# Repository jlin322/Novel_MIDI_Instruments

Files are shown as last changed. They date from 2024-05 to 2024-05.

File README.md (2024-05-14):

# Novel_MIDI_Instruments

## Overview
ECD 423 Novel MIDI Instruments is a Senior Capstone Project from 2023-2024. The purpose of this project was to design a creative Novel MIDI Instrument capable of polyphony, pitch bend and variable volume control. The product would utilize the functions of a synthesizer. This project is using the open-source synthesizer, Element. The general design consists of a detachable L-shaped rail which can fit on any ordinary tripod boom mic stand. The product consists of 2 keypads and a base station. The base station contains a tilt detection system and is fixed to the center of the rod. Depending on the location of the keypad on the rail, both keypads’ orientation as well as angle of rod tilt, the MIDI device is able to switch between different instruments. The 2 keypads are able to freely slide up and down the rod and act as the inputs for the user to control the available instruments on the mic stand. The entire system consists of 3 microcontrollers and 3 nRF24L01 transceiver modules. The transceiver modules create a long signal transmission line which works to send MIDI signals from the moment the user presses on a key or input device to the moment a note is emitted from the synthesizer.

## Final Design Product

<p float="left">
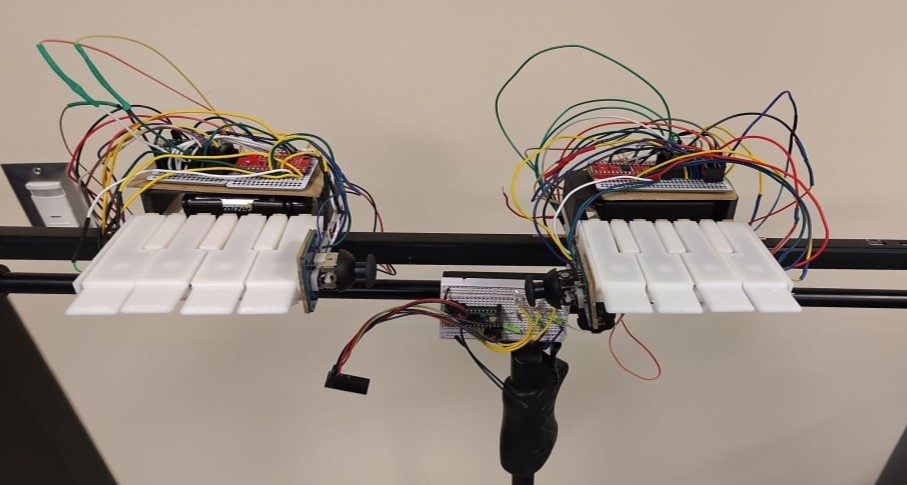
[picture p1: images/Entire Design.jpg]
 
</p>
An image of the Novel MIDI Instrument with both keypads and base station assembled on the tripod boom mic stand.

## Arduino IDE Setup

### Libraries Installation
1. **Control Surface Library by tttapa**
2. **Joystick by Giuseppe Martini**
3. **RF24 by TMRh20**
4. **light_CD74HC4067 by SunitRaut**
5. **Encoder by Paul Stoffregen**
6. **SPI**

### Code Upload

1. Upload the code from `FinalTest_TxL` to the left keypad.
2. Upload the code from `FinalTest_TxR` to the right keypad.
3. Upload the code from `FinalTest_Rx` to the base station.

### Plugin and Synthesizer Setup

1. Download all plugins from the provided plugin folder.
2. Download the synthesizer program "Kushview Element."
3. Open `NovelMIDISynth.els` from the Synthesizer Plugins & Session Folder in Element.

### Synthesizer Configuration

1. In Element, navigate to `File` > `Preferences` > `MIDI` and select "Control Surface Library" if not already chosen.
2. Exit the preferences screen and double-click on the MIDI Monitor as shown in Figure i below.

<p float="left">
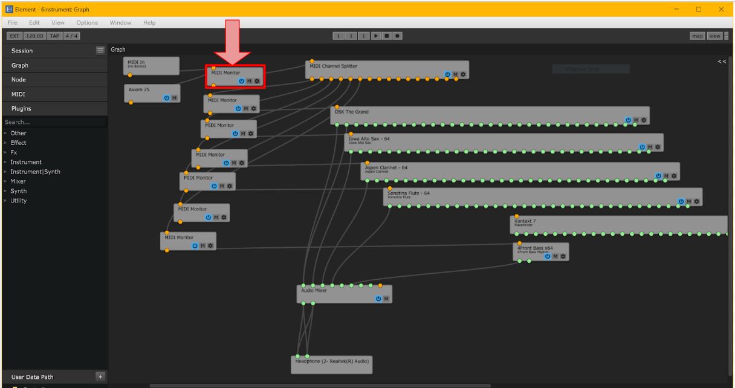
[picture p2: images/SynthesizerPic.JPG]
 
</p>
The image above shows the connections for all plugins within the synthesizer program.
By following these steps, you'll have the necessary components installed, codes uploaded, and synthesizer configured for your project.

## Credits
- Team Members: Sean MacHaffie, Rohan Giridharan, Baron Li

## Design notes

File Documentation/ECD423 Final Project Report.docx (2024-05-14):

# ECD423 Novel MIDI Instrument

# Project Report

2024-05-03

Submitted by:

Sean MacHaffie, Project Lead, Computer Engineering

Baron Li, Finance Manager & Testing Lead, Computer Engineering

Jolin Lin, Software Lead, Computer Engineering

Rohan Giridharan, Electrical & Communication Lead, Electrical Engineering

Project Advisor: Prof. Scott Craver

Approved for public release; distribution is unlimited.

Submitted in partial fulfillment of ECD academic requirements.

Thomas J. Watson College of Engineering and Applied Science

Binghamton University

Binghamton, NY

Abstract

ECD 423 Novel MIDI Instruments is a Senior Capstone Project from 2023-2024. The purpose of this project was to design a creative Novel MIDI Instrument capable of polyphony, pitch bend and variable volume control. The product would utilize the functions of a synthesizer. This project is using the open-source synthesizer, Element. The general design consists of a detachable L-shaped rail which can fit on any ordinary tripod boom mic stand. The product consists of 2 keypads and a base station. The base station contains a tilt detection system and is fixed to the center of the rod. Depending on the location of the keypad on the rail, both keypads’ orientation as well as angle of rod tilt, the MIDI device is able to switch between different instruments. The 2 keypads are able to freely slide up and down the rod and act as the inputs for the user to control the available instruments on the mic stand. The entire system consists of 3 microcontrollers and 3 nRF24L01 transceiver modules. The transceiver modules create a long signal transmission line which works to send MIDI signals from the moment the user presses on a key or input device to the moment a note is emitted from the synthesizer.

Table of Contents

1 Introduction 1

1.1 System Overview 1

1.2 Document Overview 1

2 Referenced Documents 1

3 Problem Definition 1

3.1 Problem Scope 1

3.2 Technical Review 2

3.3 Design Requirements 2

3.3.1 Original Proposed Requirements 2

3.3.2 Derived Requirements 2

3.3.3 Stretch Goals 2

4 System Design 3

4.1 System-Wide Design Decisions 3

4.2 System Components and Interfaces 5

4.3 Concept of Execution 6

4.4 Hardware Design 7

4.5 Software Design 9

4.6 Safety Considerations 11

4.7 Environmental Impact 11

5 Project Development 11

5.1 Risk Abatement 11

5.2 Project Schedule 12

5.3 Project Finances 12

6 System Implementation 13

7 Project Evaluation 13

7.1 Overview 13

7.2 Testing and Results 13

7.3 Assessment 13

7.4 Future Potential 13

8 Notes 14

8.1 Acronyms and Abbreviations 14

8.2 Bibliography 14

8.3 References 14

9 Appendices 15

9.1 Appendix A - Project Specifications Document 15

9.2 Appendix B - Financial Status Table 17

9.3 Appendix C - Code for Base Station(Receiver) 19

9.4 Appendix D - Code for Left Keypad(Transmitter) 59

9.5 Appendix E - Code for Right Keypad(Transmitter) 63

9.6 Appendix F - INT Plan 67

9.7 Appendix G - Demonstration Saxophone Fingering Chart 77

9.8 Appendix H - Parts List 86

9.9 Appendix I - Project Standards 86

9.10 Appendix I - Requirements Impact Assessment 87

List of Figures

Figure 1: Top Plate

Figure 2: Base Plate

Figure 3: High Level Keypad Design

Figure 4: High Level Base Station Keypad Design

Figure 5: Final Keypad Design, showing the 4 lamellophone keys at the bottom and the location of the pitch bend joystick

Figure 6: Preliminary Keypad Design, modeled off a traditional keyboard

Figure 7: Second Keypad Design

Figure 8: Outermost white keys, including lamellophone key attachments. At the back is a hook to attach a rubber band. There is a corresponding hook on the base plate.

Figure 9: Center white keys. These two keys are a slightly different shape than the outermost keys, allowing them to fit better in the base plate

Figure 10. Black key. All keys have a post at the front, which allows them to make proper contact with the force sensitive resistors below

Figure 11. Data Structure that is received by the base station.

Figure 12. Data Structure that holds variables for each key and determines which notes are going to be sent to the synthesizer.

Figure 13. Gantt Chart for the Fall Semester

List of Tables

Table 1. Order Breakdown

# 1 Introduction

## 1.1 System Overview

This report is for the ECD423 Novel MIDI Instrument project of 2023-2024.

The purpose of this project is to create a Novel MIDI Instrument that is capable of polyphony, variable volume control and pitch bend. The design can be described as a detachable metal rail with 2 sliding keypads, a tilt detection system and a base station which is attachable to the lifting tube of the microphone stand. The base station sends signals to the synthesizer via USB connection. The device is capable of being attached to a tripod boom microphone stand without inhibiting the microphone stand's original functionality. The user is able to play a variety of instruments on the microphone stand. Keypad rotation, keypad location on the rail and rod tilt are taken into account in order to switch between different instruments. The user is able to control the type of notes being produced by the synthesizer using keys on the keypad as well as location of the keypad on the rail. Sliding the keypads up and down the rod can produce note changes depending on what instrument is being played.

## 1.2 Document Overview

This report provides the essential project requirements in Section 3, Requirements, along with some non-essential stretch goals.

In this specification, a requirement is identified by “shall”, a good practice by “should”, permission by “may” or “can”, expected outcome or action by “will”, and descriptive material by “is” or “are” (or another verb form of “to be”).

# 2 Referenced Documents

The following documents of the exact issue shown form a part of this report as specified herein.

A. ECD423: Novel MIDI Instrument Project Specifications Document

# 3 Problem Definition

## 3.1 Problem Scope

For musicians, there exists the problem of practicality when playing multiple instruments at the same time. This problem becomes more prevalent for people who enjoy playing as one man bands. Time wasted having to set up each individual instrument on stage, along with having to switch from one musical device to another as well as the difficulty of having to carry these instruments from place to place proves challenging and impractical. The goal of this project is to design and create a Novel MIDI Instrument capable of polyphony, pitch bend and variable volume control. The final product is able to imitate the abilities of a typical instrument as well as switch between multiple different instruments as well.

## 3.2 Technical Review

The device was created with the intent of being an attachable object onto a typical microphone stand. The product should not inhibit the functions of a regular microphone stand whilst imitating instruments. One advantage that the consumer should notice includes time efficiency when switching from 1 instrument to another. For example, the user would simply need to tilt the metal rod 90 degrees, allowing it to point upwards towards the ceiling, and rotate the left keypad 180 degrees to transition from piano mode to bass guitar mode. This is assuming that the position the user was in prior to the transition allowed the device to be in piano mode. Another advantage includes the ease of learning how to use this product. Since the design is a collection of ordinary musical instruments, users will rarely feel like they need to learn an entirely different skill set to play this device. The instrument modes available on the device were designed to take after the orientation of the instruments and the positioning of the hands for a typical person playing that specific instrument. In this way, users need only remember how they would typically play an instrument and imitate that on the Mic Stand.

## 3.3 Design Requirements

The contents below contain the original/derived requirements and stretch goals. A tabled version of this is included in the Appendix section of this document.

### 3.3.1 Original Proposed Requirements

1. The MIDI instrument shall be able to produce polyphony, pitch bend and variable volume control. {ECD423-R-001}
2. The MIDI instrument shall be able to produce pitch bend. {ECD423-R-002}
3. The MIDI instrument shall be able to produce variable volume control. {ECD423-R-003}
4. It shall output accurate MIDI signals to the synthesizer. {ECD423-R-004}

### 3.3.2 Derived Requirements

1. The device shall not inhibit the functions of an ordinary microphone stand. {ECD423-R-005}
2. Both keypads will be capable of rotation and sliding movement on the rod. {ECD423-R-006}
3. The device shall be able to switch between at least 6 different instruments based on keypad rotation, keypad location on the rod, and rod tilting motion. {ECD423-R-007}
4. There shall be wireless communication between the keypads and base station. {ECD423-R-008}
5. The device shall be able to detect the position of both keypads on the rod at any given time. {ECD423-R-009}
6. The base station shall have the capability to differentiate between 3 positions on the rod: horizontal, vertical and angled. {ECD423-R-010}
7. MIDI signals shall travel from the base station to a synthesizer via USB connection. {ECD423-R-011}

### 3.3.3 Stretch Goals

1. The response time between note pressing and note emission from the synthesizer should be less than 10ms. {ECD423-G-001}
2. The instrument should be able to synthesize sound directly from the product. {ECD423-G-002}
3. Both keypads should have an electronic locking/unlocking mechanism to secure its position on the rod when locked and allow for movement when unlocked. {ECD423-G-003}
4. The device should be able to switch between at least 10 different instruments based on keypad rotation, keypad location on the rod, and rod tilting motion. {ECD423-G-004}
5. The device should have 4 lamellophone style keys which are attached to force sensors and produce sound reminiscent of strumming string instruments. {ECD423-G-005}

# 4 System Design

## 4.1 System-Wide Design Decisions

    4.1.1 Keypad Position: For deciding how to measure the keypads position along the rod there were three options: digital caliper, rotary encoder, and optical mouse sensors. The rotary encoder was chosen for ease of use. Using a readily available Encoder library, the rotary encoder was easily interfaced with the Teensy microcontroller. As the technology of an PS2 optical mouse is more outdated, it was difficult to find a suitable mouse and library. The final option was to imitate a digital caliper. There are no readily available components to make this option possible. This option was dismissed due to time constraints.
    4.1.2 Tilt Detection: To measure rod tilt, there were 3 different options. The first option was a mercury tilt sensor, a time-of-flight sensor, and a metal ball tilt sensor. The option that was chosen was the metal ball tilt sensor. This option was chosen due to the simplicity of its implementation. The mercury tilt sensor was dismissed due to environmental concerns, in case the sensor were to break.. The time-of-flight sensor was difficult to connect with the base station in an accurate way. The constantly changing environment of the tilting microphone stand caused inaccurate measurements.
    4.1.3 Key Measurement: To measure variable volume, the project utilizes force sensitive resistors. These were chosen due to the ease of implementation. Pushing on these force sensitive resistors with the piano keys gives a variable analog value based on the force of the key press. This analog value was easily tied to the variable volume in the synthesizer software.

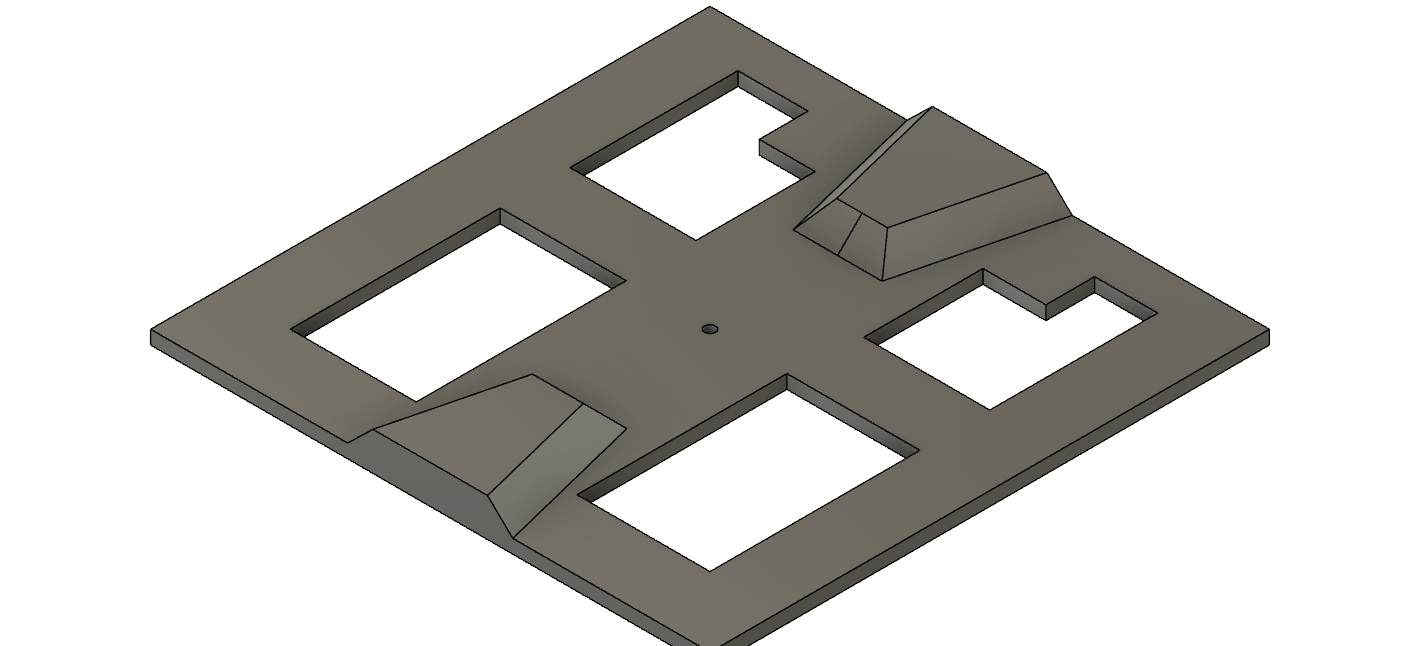
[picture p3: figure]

Figure 1: Top Plate

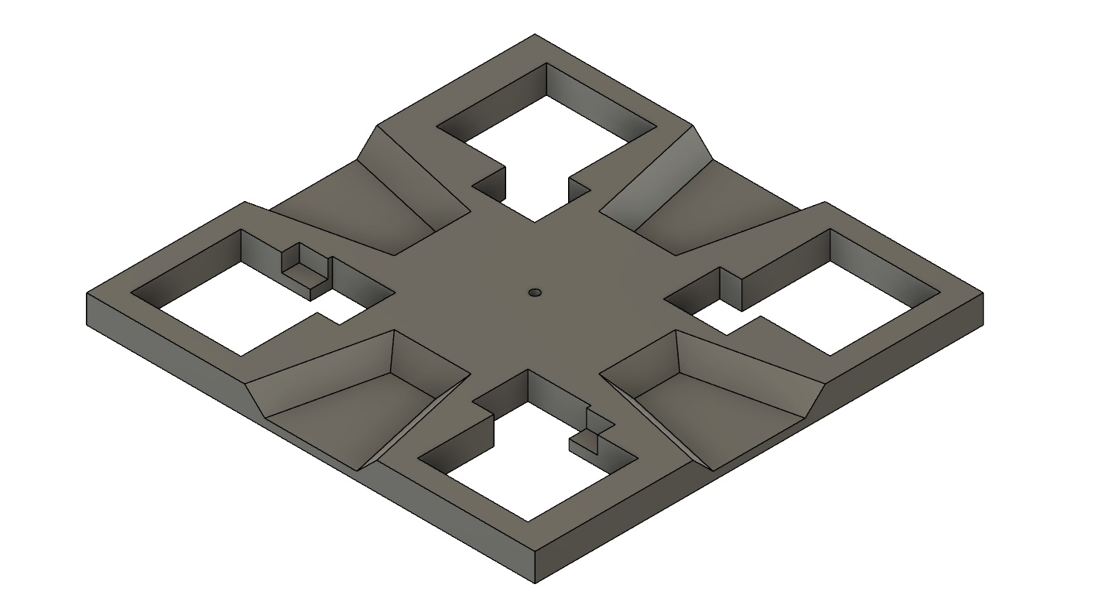
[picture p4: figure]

Figure 2: Base Plate

    4.1.4 Rotation: The device has rotating keypads. To accomplish this the keypad has a rotation base plate and top plate shown in figure 1 and 2 respectively. The top plate has contacts that are connected to pull-up resistors which will identify four different rotation positions (up, down, left, right).

## 4.2 System Components and Interfaces

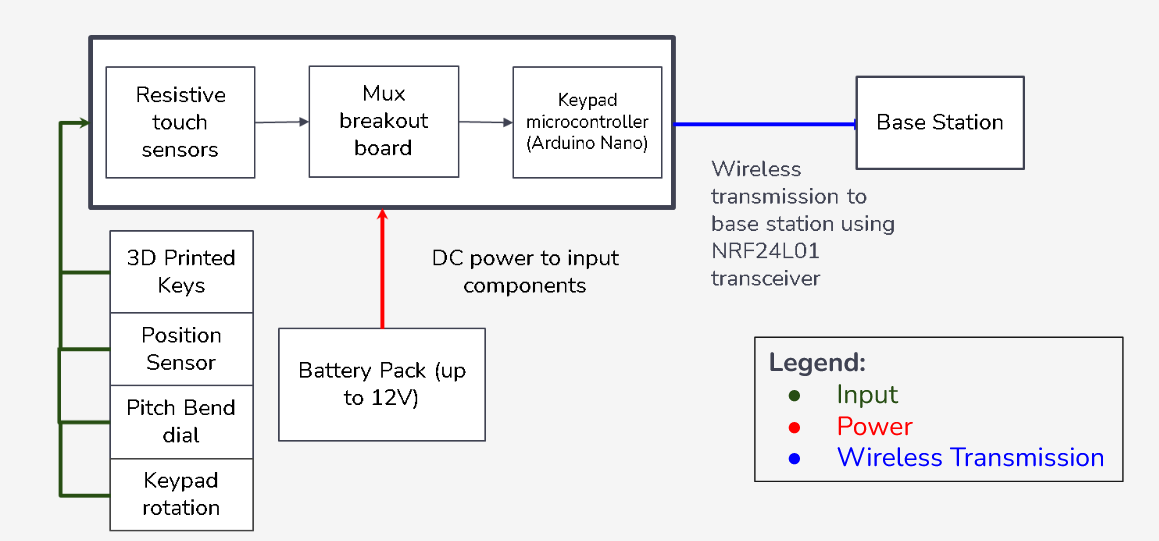
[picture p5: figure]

Figure 3: High Level Keypad Diagram

    4.2.1 Keypad: The instrument has two sliding keypads. Each keypad will contain seven force sensitive resistors, one rotary encoder, one NRF2401 wireless transceiver, one analog multiplexer breakout board, one two-axis joystick, and one microcontroller. The microcontroller takes all the inputs and sends them to the base station in a struct. The microcontroller was chosen for its small form factor. The multiplexer breakout board is implemented to allow enough input ports for the keypad components. The seven force sensitive resistors (FSR) are implemented under the seven 3D printed keys. Each FSR provides an analog signal to the microcontroller board, and just as in a traditional keyboard, the harder the key is pressed, the louder the note that is played. The left keypad’s two-axis joystick is used for pitch bend, while the joystick on the right keypad is used to mimic a breath in the woodwind modes. The joysticks are located on the side of the keypad, intended to be positioned under a users’ thumb on each keypad. The NRF24L01 transceiver module is used to wirelessly transmit data. A rotary encoder outputs a value that will increase or decrease to indicate which direction it is turning. The software constantly updates this value starting from a known zero position to accurately track the position of the keypad with this method.

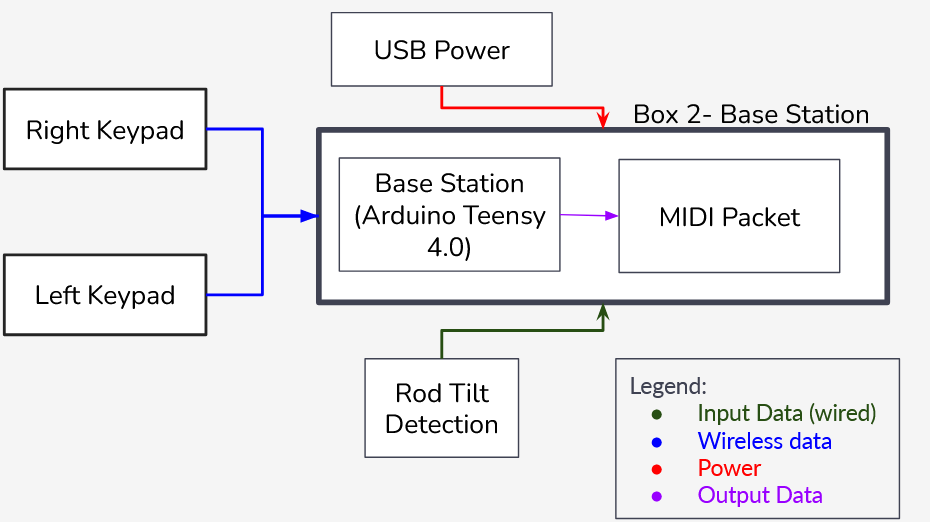
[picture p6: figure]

Figure 4: High Level Base Station Keypad Diagram

    4.2.2 Base Station: The instrument has one base station. The base station will use an Arduino Teensy 4.0 microcontroller. The Teensy was chosen for its USB communication capability and its size. The purpose of the base station is to receive wireless data from the keypads. Additionally, the base station has three metal ball tilt sensors that are used to determine the tilting mode of the instrument, whether it be horizontal, vertical or tilted. By combining the tilt motion with the position and rotation of the keypad, this allows the user to change to a number of instruments. Using the MIDIUSB Arduino library, the base station creates a MIDI message which will be sent over USB to the external synthesizer software Element and outputted over the computer speakers.

## 4.3 Concept of Execution

The target audience uses the MIDI device via interactions with the 2 keypads which rests on the detachable rail. The keypads are ergonomically designed for the left and right hands. The user can determine the orientation of each keypad based on the location of the joystick which is attached to the inside of the keypads. Ideally, the correct orientation of the left keypad for the consumer is one where the joystick is located on the right side of the keypad and the keys are faced in a similar way like a piano. In the instance where the device is in piano mode, this means that the user has allowed the rail to run parallel to the ground with both keypads facing towards him. The device recognizes the switching to this particular instrument mode in part due to the tilt detection system which is made up of tilt switches that turn on and off when the rod is at different angles. The location of the keypad on the rail serves as a crucial aspect in this design. The user can play a variety of notes similar to that of a piano when in piano mode. The inner workings to make this possible involve the transmission of signals produced when the user hits a key. A signal gets generated and travels through an Arduino Nano to a wireless transceiver which then is accepted by a receiver on the base station to a Teensy where the MIDI signal is finally sent to the synthesizer for the correct note to be emitted. This isn’t the only thing that is sent through the transmission line because underneath each key lies a force resistive sensor which collects the pressure exerted by the user on the keys. The range of pressure applied to these keys controls the volume at which the user wants to emit the notes at. The consumer would only need to exert more pressure when wanting to evoke a louder note and exert less pressure for the opposite effect. Moving the joystick in different directions allows the audience to control pitch bend to produce a musical effect of notes sliding into other notes. This information is also sent along the transmission line to be unpackaged and in the Teensy. Since the keypads communicate wirelessly, each keypad will have a rechargeable battery while the base station is powered by the laptop via USB connection. To break this connection and shut off the system, the user only needs to disconnect the laptop from the base station.

## 4.4 Hardware Design

All 3D models for hardware components were made in Autodesk Fusion 360. This includes the following: white and black keys, a keypad base, rotation mechanism (shown in section 4.1.3) and a slider attachment. While brainstorming, there were multiple keypad designs before the final design shown in Figure XI. The first design was modeled off what would be found on a traditional keyboard, which is shown in figure XII. The lamellophone design was chosen as it would allow the user to be able to play instruments like a bass or a guitar, which require a plucking or strumming motion. This design is not conducive to strumming, and would therefore be extremely impractical and difficult to implement. Implementing this design would also result in a lot of additional hand movement to change the set of notes that were being played. The second design (Figure XIII) consisted of 5 white keys and 4 black keys, where the black keys would be positioned in such a way that they could be used as an analog for the strumming instruments. The black keys would be sufficiently high above the white keys and would require a spring mechanism that could provide a somewhat stringlike motion. While far more practical than the first design, implementing this design would have required a lot of testing to find not only the right kind of spring, but also the necessary actuation force. This would have taken up a lot of valuable time during the spring semester. The current design is a refinement of design 2, adding the lamellophone keys at the bottom of the keypad to imitate a string instrument, as well as a joystick for pitch bend on the side, in reach of the user’s thumb. After coming up with the final keypad design, the models were created for the keypad base, and the black, white and lamellophone keys. There are three different versions of the white keys, one for the left side, one for the right side and one for the two center keys. At the end of the white and black keys, there is a hook, which will be used as an attachment point for the rubber bands to ensure the key returns to its original position after being pressed. Rather than use a spring, rubber bands were used as the actuation force could be easily tuned by simply changing the amount of rubber bands, rather than swapping out the entire spring. As was the case with keypad design 2, this will ultimately save a lot of time while testing. All keys have a post at the front, which allows them to make proper contact with the force sensitive resistors (FSRs) below. As with a traditional piano, the harder you press on the keys, the louder the sound of the note.

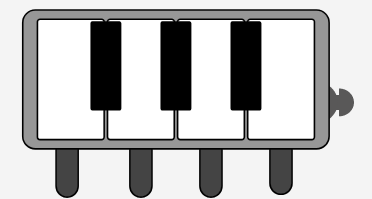
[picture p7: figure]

Figure 5: Final Keypad Design, showing the 4 lamellophone keys at the bottom and the location of the pitch bend joystick

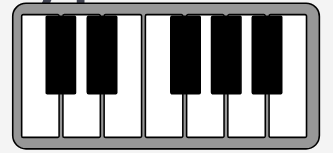
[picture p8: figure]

Figure 6: Preliminary Keypad Design, modeled off a traditional keyboard

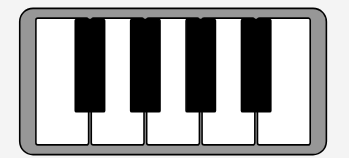
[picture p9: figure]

Figure 7: Second Keypad Design

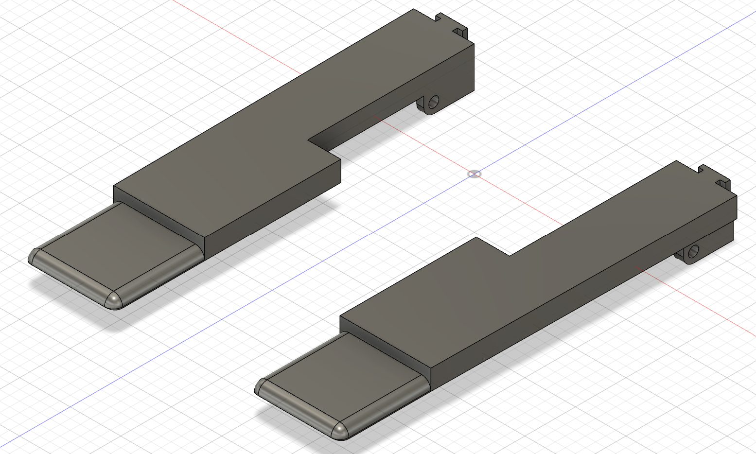
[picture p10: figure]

Figure 8: Outermost white keys, including lamellophone key attachments. At the back is a hook to attach a rubber band. There is a corresponding hook on the base plate.

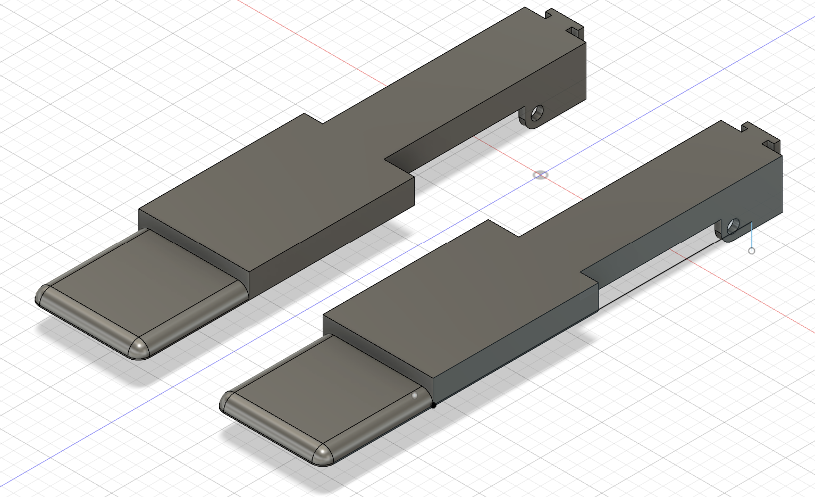
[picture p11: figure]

Figure 9: Center white keys. These two keys are a slightly different shape than the outermost keys, allowing them to fit better in the base plate

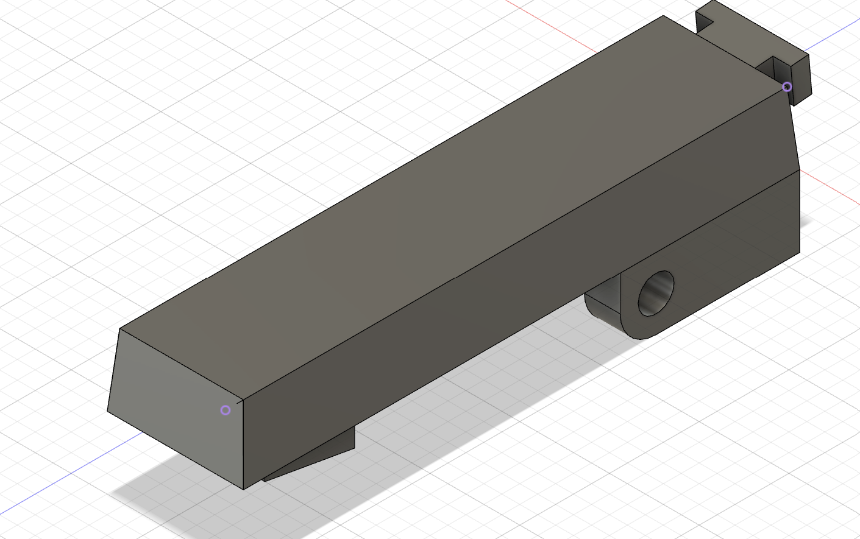
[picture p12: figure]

Figure 10: Black key. All keys have a post at the front, which allows them to make proper contact with the force sensitive resistors below

## 4.5 Software Design

All software that was constructed was created using Arduino IDE. The final programmed files were only created after running multiple demos which involved manipulating a set of test signals to send them to their ultimate destination, the Element synthesizer. Demo code for this project started off with MIDI signals traveling close to the synthesizer relative to the entire transmission line that the signal would eventually have to pass through from start to finish. The program experimented with using a backwards approach by first sending MIDI signals from the base station micro controller to the synthesizer directly through a USB connection. Wireless communication between the base station and keypads were established with two nRF24L01 set to transceiver mode in the keypads and the final nRF24L01 set to receiver mode in the base station. This allowed consistent one directional communication between the keypads and the base station when the system was on. Code was then generated once the Arduino Nano’s on each keypad were connected to the wireless transceivers to send test signals starting from the Nano and traveling through the transmission pipe to the synthesizer. The final step in this was performed through a combination of circuitry knowledge and programming skills, as the test signals no longer needed to be hard coded onto the board. Rather a test user would press on the keys themselves to generate signals. The same was done for the joysticks. During this entire process, all demo programs were consolidated into one location with proper formatting and comments for readability and correct interpretation of program intent.

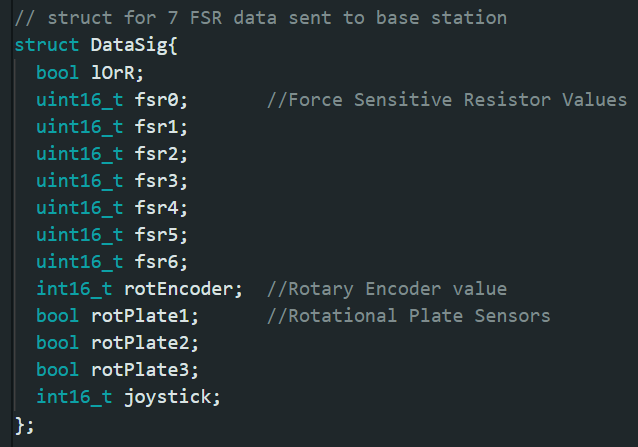
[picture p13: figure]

Figure 11: This is the data structure that is received by the base station.

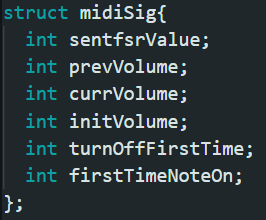
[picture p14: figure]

Figure 12: This structure holds variables for each key and determines which notes are going to be sent to the synthesizer.

The final code contains three general programs which had to be uploaded to both keypads and the base station. Please note that the file name demo13_finalTestTxL contains code for the left keypad while demo13_finalTestTxR is meant for the right. Since both keypads differ slightly by the soldering of different pins, both keypads must have independent files. Moving on, the file demo13_finalTestRx is code for the receiver or base station. In summary, the receiver code takes data signals from both transmitters and saves them in separate structures. Data within these structures use the switchInstruments() function to determine which instrument setting the device is on. Depending on the instrument mode, certain functions may be invoked which ultimately determine the instructions to send to the synthesizer. Instructions that may be used include sending notes on or off, which notes to play, what instrument channel to play them with, what volume to play it on and whether there is pitch bend or not.

## 4.6 Safety Considerations

In the brainstorming process of the novel instrument, ensuring safety was a key consideration in the design discussion. Instead of employing mercury tilt switches for the rod tilt detection, the design opts for metal ball tilt switches. Mercury is classified as a toxic heavy metal. In consideration of health and environmental concerns, the mercury tilt switches were excluded from consideration. All wiring will be discreetly embedded within the instrument housing, eliminating potential environmental hazards with exposed wires.

## 4.7 Environmental Impact

As mentioned in the safety considerations, the environmental impact was an important consideration when designing the instrument. The metal ball tilt switches do not have the same environmental risk of mercury contamination. The keypads will be powered with a rechargeable battery pack. This choice was made with sustainability in mind, and eliminates the need for battery replacements and minimizes the waste in comparison to single-use disposable batteries. The housings and keypads are created with CAD and printed with ABS plastic, a commonly used thermoplastic in 3D printing. ABS plastic is durable, safe for consumer use, and can be melted and recycled.

# 5 Project Development

## 5.1 Risk Abatement

Some risks that may affect this project are: integration of many different hardware components, too many inputs into the microcontroller, and total propagation time from note press to sound output. To mitigate these risks, all components are tested and verified separately before integration. All ordered components must also be well-documented. To resolve the potential error of not having enough inputs into the microcontroller, a multiplexer breakout board was procured. To mitigate the propagation time, a low latency wireless standard was selected. The design utilizes low latency components such as the NRF24L01 transceiver.

## 5.2 Project Schedule

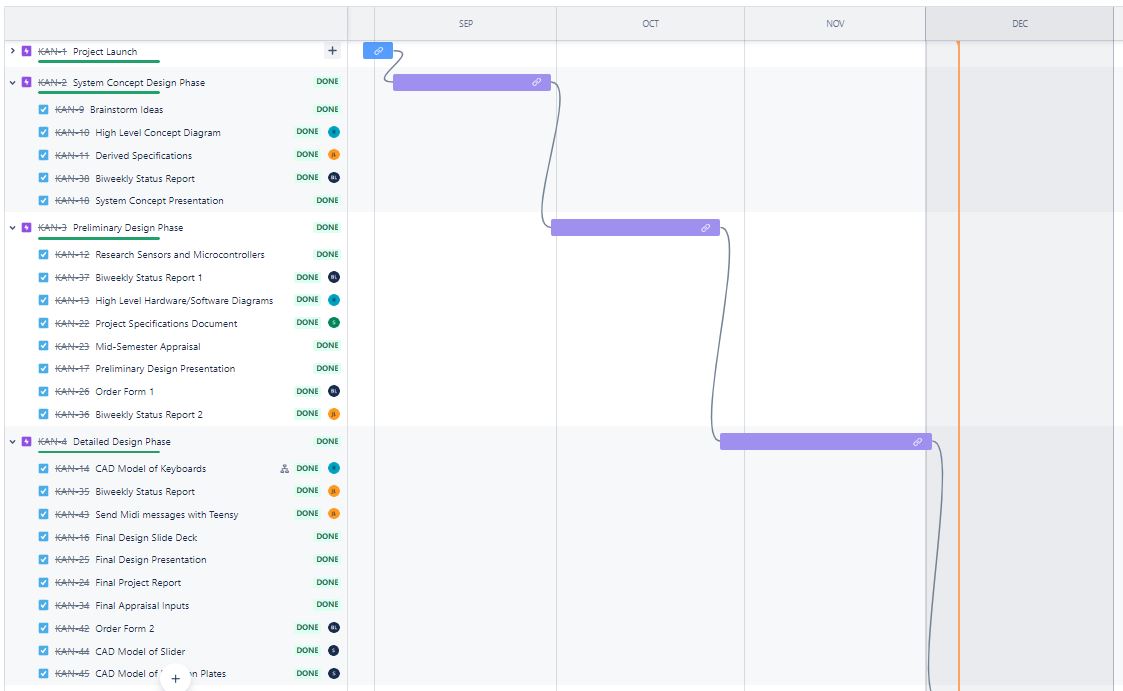
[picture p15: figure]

Figure 11: Gantt Chart for the Fall Semester

The project was formally launched on September 1st, 2023. After a brainstorming process, a list was compiled for September.. Research for sensors began in October and early CAD designs for housing components were proposed. The team created high level software and hardware diagrams. The design was finalized in early November, as testing began for some of the sensors and components. Test programs for the MIDI synthesizer and controller were made to successfully generate MIDI signals using the Arduino Teensy and the Element software. Final keys and keypad designs were made and ready to be printed. Throughout the Spring semester, the sensors were integrated into the base station and keypads. After integrating the components together on the microphone stand, thorough testing, calibrating and debugging was done to finalize the prototype.

## 5.3 Project Finances

A budget of $800 has been allocated to the project’s fulfillment. Electronic equipment and materials were provided by the Seymour Kunis Media Core. A breakdown of the order cost can be seen in Appendix B. As the Novel MIDI Instrument designed for this project was complex, it had surpassed the expected expenditure of $150 - $200 as seen in previous iterations of the project. Due to the high cost of the required sensors and the extensive testing for optimal and compatible components, a total of approximately $400 was spent. As not all of the ordered sensors were used in the final design, the cost of the prototype would be closer to $200.

# 6 System Implementation

The final design contains the 2 keypads with a base station. The electronics of the keypads were assembled with a soldered project board, with some pin extenders that were used to plug in some components so they could be removable. This was done to the Teensy that is on board along with the pins for the rotary encoder, the pins for the NRF24L01 transceiver and battery.

For better use of the rotary encoder, a gear was attached on the knob of the encoder and a track along the rail to ensure that no rotations were missed when the keypad moved along the rod. to attach the keypads top and bottom plate, a screw attached to an U shaped piece of 3d printed plastic which acted as a spring. This ensured that the top plate had enough pressure to attach to the base plate but could be lifted and rotated by the user.

To power the keypads, AA batteries were used. Due to the limited supplies of the Seymour Kunis Media Core, one keypad was powered by 4 AA batteries and the other keypad was powered by 3 AA batteries. The 4 AA batteries worked better due to a longer battery life and better counter weight for the keypad.

For the actual keyboard, a 10-gauge wire was inserted as an axle for all the individual keys to rest on. Orthodontic elastic bands functioned well with the axle to keep the keys in a default position. The bands were also readily available in the Media Core. A spacer was added below the keypad so the bands can be changed after assembly.

The base station and the tilt sensor were combined into one unit for simplicity. The tilt sensor was left on a solderless breadboard due to the position of the metal ball tilt switches being very important. This station was attached to the rod with some trouble sided tape.

# 7 Project Evaluation

## 7.1 Overview

To evaluate this project, it was demonstrated that each test could be independently performed. After proving successful, the goal was to integrate the systems to test again.

An example of this would be testing wireless communication between two microcontrollers, then performing the test again with an assembled keypad unit and base station. Due to unforeseen integration issues, the verification phase did not end until April 15th, 2024. While many of the tests were met, there were lapses in reliability that would cause the test to fail occasionally. Overall, the major requirements were all met and most of the derived requirements.

## 7.2 Testing and Results

A list of tests and how they were performed can be found in Appendix F. The instrument was able to reliably detect the three levels of tilt. The rotary encoder could read the rolling along the rod with minimal error. The rotation system was able to detect 4 different positions, however it only worked well on a flat surface. Wireless communication was able to send and receive messages in the allotted time frame.

## 7.3 Assessment

The instrument was able to meet all of the given requirements. It could accurately and reliably submit MIDI messages to a synthesizer, do variable volume, polyphony and pitch bend. The instruments did meet most of the derived requirements. The instrument is capable of switching between 6 different instruments but could only reliably switch between 4 of the instruments. Wireless communication using an NRF24l01 transceiver between the base station and the keypads was successful. No permanent changes to the microphone stand were required in the prototype’s implementation. Due to time constraints, not all of the stretch goals were met. The lamellophone key stretch goal was met. The design did have some reliability issues that did cause issues when demonstrating the capabilities of the instrument.

## 7.4 Future Potential

As future groups are expected to design a new novel MIDI instrument, there will be no future modifications. If this design was revisited in the future, potential changes and improvements would involve creating a more stable design, increasing the accuracy of the sensors and integrating more instruments in software.

# 8 Notes

## 8.1 Acronyms and Abbreviations

ECD ECE Capstone Design

ECE Electrical and Computer Engineering

MIDI Musical Instrument Digital Interface

## 8.2 Bibliography

Not applicable.

## 8.3 References

[1] Teensyduino: Download and Install Teensy support into the Arduino IDE. (2017). Pjrc.com. https://www.pjrc.com/teensy/td_download.html

[2] Getting Started with the Teensy - SparkFun Learn. (2018). Sparkfun.com. https://learn.sparkfun.com/tutorials/getting-started-with-the-teensy/programming

[3] ada, lady. (2012, July 29). Tilt Sensor. Adafruit Learning System. https://learn.adafruit.com/tilt-sensor/overview

[4] RP-C18.3-ST Thin Film Pressure Sensor SKU:SEN0294. (n.d.). Retrieved December 7, 2023, from https://mm.digikey.com/Volume0/opasdata/d220001/medias/docus/695/SEN0294_Web.pdf

# 9 Appendices

## 9.1 Appendix A - Project Specifications Document

ECD Project Specification Document

ECD423 Novel MIDI Instrument

Project Description

Summary: The premise of this project is to design a creative and unique MIDI interface that is able to imitate a variety of musical instruments. The MIDI device must be able to have polyphony, demonstrate variable volume control and be capable of pitch bend. Due to the obscurity of this project, a major portion of the time spent on this proposal will be spent brainstorming potential ideas. Continuous experimentation and trials will take place throughout the entire design process to guarantee the optimal usability of each component in this project.

Sponsor: N/A

Industry Mentor (if applicable): N/A

Project Advisor: Professor Scott Craver

Team: Sean MacHaffie, Baron Li, Rohan Giridharan, Jolin Lin

Requirements

This document lists all essential project requirements for this project. A requirement is identified by “shall”, a good practice by “should”, permission by “may” or “can”, expected outcome or action by “will”, and descriptive material by “is” or “are” (or another verb form of “to be”).

The following Qualification Method (QM) is to be used:

- Demonstration (D): The operation of the system, or a part of the system, that relies on observable functional operation not requiring the use of instrumentation, special test equipment, or subsequent analysis.
- Test (T): The operation of the system, or a part of the system, that uses instrumentation or other special test equipment to collect data for analysis.
- Analysis (A): The processing of data obtained from another qualification method. For example, reduction, interpolation, or extrapolation of test results.
- Inspection (I): The visual examination of system components, documentation, etc.

The following Requirement Categories (RC) are to be used:

- System Capability Requirements (SC): Requirements pertaining to the functionality and behavior of the system.
- System External Interface Requirements (EI): Requirements based on the external interfaces of the system. Interfaces with input power, user input, or any other outside source
- Project Business Requirements (PB): Requirements pertaining to business objectives set by a sponsor such as installation requirements, requirements pertaining to specific lab access or lab equipment needs etc.
- Other Requirements (O): Safety, Security and Privacy, System Environment concerns etc.

2.1 Derived Requirement Specification

ID | QM | RC | Derived Requirement
ECD423-R-001 | D | SC | The MIDI instrument shall be able to produce polyphony.
ECD423-R-002 | D | SC | The MIDI instrument shall be able to produce pitch bend.
ECD423-R-003 | D | SC | The MIDI instrument shall be able to produce variable volume control.
ECD423-R-004 | I | O | It shall output accurate MIDI signals to a synthesizer.
ECD423-R-005 | I | SC | The device shall not inhibit the functions of an ordinary microphone stand.
ECD423-R-006 | D | SC | Both keypads will be capable of rotation and sliding movement on the rod.
ECD423-R-007 | D | SC | The device shall be able to switch between at least 6 different instruments based on keypad rotation, keypad location on rod, and rod tilting motion.
ECD423-R-008 | I | SC | There shall be wireless communication between the keypads and base station.
ECD423-R-009 | A | SC | The device shall be able to detect the position of both keypads on the rod at any given time.
ECD423-R-010 | I | SC | The base station shall have the capability to differentiate between 3 positions on the rod: horizontal, vertical, and angled.
ECD423-R-011 | T | EI | MIDI signals shall travel from the base station to a synthesizer via USB connection.

2.2 Derived Stretch Goals

ID | QM | RC | Stretch Goals
ECD423-G-001 | T | O | The response time between note pressing and note emission from the synthesizer should be less than 10ms.
ECD423-G-002 | I | EI | The instrument should be able to synthesize sound directly from the product.
ECD423-G-003 | I | SC | Both keypads should have an electronic locking/unlocking mechanism to secure its position on the rod when locked and allow for movement when unlocked.
ECD423-G-004 | D | SC | The device should be able to switch between at least 10 different instruments based on keypad rotation, keypad location on rod, and rod tilting motion.
ECD423-G-005 | I | SC | The device should have 4 lamellophone style keys which are attached to force sensors and produce sound reminiscent of strumming string instruments.

2.3 Original Proposed Requirements

QM | RC | Original Requirement
D | SC | The MIDI instrument shall be able to produce polyphony.
D | SC | The MIDI instrument shall be able to produce pitch bend.
D | SC | The MIDI instrument shall be able to produce variable volume control.
I | EI | It shall output accurate MIDI signals to a synthesizer.

## 9.2 Appendix B - Financial Status Table

## 9.3 Appendix C - Code for Base Station(Receiver)

/*

Programmer: Jolin Lin

ECD 423 - Novel MIDI Instrument (Senior PRJ)

Date: 04/24/2024

Purpose: This is the program to ran during the Expo(04/26/2024).

The purpose of this file is to be uploaded to the receiver/base station.

It takes in data signals sent from both transmitters/keypads to switch btw

instruments in the synthesizer, have variable volume and polyphony.

Notes:

*/

#include <SPI.h>

#include <RF24.h>

#include <Control_Surface.h>

#include <print.h>

#define SIZE 3 //size of volume history

#define TILTSIZE 10 //size of tilt sensor history

#define KEYNUM 7 //size of number of keys on a keypad

#define JOYSTICKUPPERLIMIT 560

#define JOYSTICKLOWERLIMIT 470

RF24 radio(9,10); // pin assignments for nRF CE,CSN

USBMIDI_Interface midi; //MIDI over USB interface object

//---------------------------------------Setup----------------------------------------------------------

const int sensorVPin = 5;

const int sensorAPin = 19;

const int sensorHPin = 20;

uint8_t pipe1 = 1; // pipe values may go from 0-6 and represents the individual

uint8_t pipe2 = 2; // paths available for 1 nRF module to be able to receive data from

//---------------------------------------Global Variables------------------------------------------------

const uint8_t velocity = 0x7F;

const uint8_t offvelocity = 0x00;

const uint8_t ccAddr = MIDI_CC::Channel_Volume; //changes control channel to ChannelVolume

int8_t tiltSensor = 0b000; //global variables associated with tilt sensor noise elimination

int cmpTilt;

int8_t sameValCount = 0;

int secondTiltVal = 0;

int tiltSensHist[TILTSIZE]; //create an array with size 10 to collect tiltSensor History that updates with every loop

int8_t iteratetiltHist= -1;

int8_t i_collectData = 0;

int8_t rotPlateHist[2] = {0,0};

int8_t startingMuxSel = 0;

int16_t maxRE = 385;

int16_t maxReRange = maxRE/6;

int16_t borderValue_L = 25; //boundary for rotary encoder to switch between clarinet and sax

//---------------------------------------Structs and Initalization----------------------------------------

//Piano and Bass Guitar: Note Addr for each Key on the Keypad

MIDIAddress noteAddr1L; //left most white key

MIDIAddress noteAddr2L;

MIDIAddress noteAddr3L;

MIDIAddress noteAddr4L; //right most white key

MIDIAddress noteAddr5L; //left most black key

MIDIAddress noteAddr6L;

MIDIAddress noteAddr7L; //right most black key

MIDIAddress noteAddr1R; //left most white key

MIDIAddress noteAddr2R;

MIDIAddress noteAddr3R;

MIDIAddress noteAddr4R; //right most white key

MIDIAddress noteAddr5R; //left most black key

MIDIAddress noteAddr6R;

MIDIAddress noteAddr7R; //right most black key

//Sax Mode: Only 1 note addr needed for sax

MIDIAddress saxNoteAddr;

MIDIAddress clarinetNoteAddr;

MIDIAddress fluteNoteAddr;

// struct for 7 FSR data sent to base station

struct DataSig{

bool lOrR;

uint16_t fsr0; //Force Sensitive Resistor Values

uint16_t fsr1;

uint16_t fsr2;

uint16_t fsr3;

uint16_t fsr4;

uint16_t fsr5;

uint16_t fsr6;

int16_t rotEncoder; //Rotary Encoder value

bool rotPlate1; //Rotational Plate Sensors

bool rotPlate2;

bool rotPlate3;

int16_t joystick;

};

//initalize struct for DataSig

struct DataSig dataSigReceivedL;

struct DataSig dataSigReceivedR;

struct DataSig tempSig;

// this struct holds variables for each key and determines which notes

// to send to the synthesizer

struct midiSig{

int sentfsrValue;

int prevVolume;

int currVolume;

int initVolume;

int turnOffFirstTime;

int firstTimeNoteOn;

};

// initialize struct for individual keys

midiSig key1DataL = {0,0,0,0,1,1};

midiSig key2DataL = {0,0,0,0,1,1};

midiSig key3DataL = {0,0,0,0,1,1};

midiSig key4DataL = {0,0,0,0,1,1};

midiSig key5DataL = {0,0,0,0,1,1};

midiSig key6DataL = {0,0,0,0,1,1};

midiSig key7DataL = {0,0,0,0,1,1};

midiSig fsrStructL ={0,0,0,0,1,1}; //temp struct for left keys

midiSig key1DataR = {0,0,0,0,1,1};

midiSig key2DataR = {0,0,0,0,1,1};

midiSig key3DataR = {0,0,0,0,1,1};

midiSig key4DataR = {0,0,0,0,1,1};

midiSig key5DataR = {0,0,0,0,1,1};

midiSig key6DataR = {0,0,0,0,1,1};

midiSig key7DataR = {0,0,0,0,1,1};

midiSig fsrStructR = {0,0,0,0,1,1}; //temp struct for right keys

// a struct to keep track of which note is on at any given time

struct noteOnHis{

bool ith_Val[KEYNUM];

char whichKeypad[KEYNUM];

};

struct noteOnHis noteOnSig = {{0,0,0,0,0,0,0}, {'N','N','N','N','N','N','N'}};

using namespace MIDI_Notes; // Define the MIDI note names and their corresponding values

//---------------------------------------Functions Start Here------------------------------------------------

// Piano: Function to produce key fade in piano mode

void fadeVolume(int ith_Val, char whichKeypad){

if(whichKeypad == 'L'){

if(fsrStructL.initVolume > fsrStructL.currVolume){

//decrease volume very fast

for(int i=fsrStructL.initVolume; i>=0; i-=10)

{

midi.sendControlChange(ccAddr, fsrStructL.initVolume); //changes CC to volume control option

// would be sending the prev. volume

chooseNoteOn(ith_Val, 'L');

}

}

else{

// decrease volume slowly

for(int i=fsrStructL.initVolume; i>=0; i-=5)

{

midi.sendControlChange(ccAddr, fsrStructL.initVolume); //changes CC to volume control option

// would be sending the prev. volume

chooseNoteOn(ith_Val, 'L');

}

}

}

else{

if(fsrStructR.initVolume > fsrStructR.currVolume){

//decrease volume very fast

for(int i=fsrStructR.initVolume; i>=0; i-=10)

{

midi.sendControlChange(ccAddr, fsrStructR.initVolume); //changes CC to volume control option

// would be sending the prev. volume

chooseNoteOn(ith_Val, 'R');

}

}

else{

// decrease volume slowly

for(int i=fsrStructR.initVolume; i>=0; i-=5)

{

midi.sendControlChange(ccAddr, fsrStructR.initVolume); //changes CC to volume control option

// would be sending the prev. volume

chooseNoteOn(ith_Val, 'R');

}

}

}

//update noteOnHis struct here

noteOnSig.ith_Val[ith_Val] = 1;

noteOnSig.whichKeypad[ith_Val] = whichKeypad;

}

// Piano: Function assigns which noteAddr gets turned on

void chooseNoteOn(int i, char whichKeypad){

if(i == (startingMuxSel)){

if(whichKeypad == 'L'){

midi.sendNoteOn(noteAddr1L, velocity);

}

else{

midi.sendNoteOn(noteAddr1R, velocity);

}

}

else if(i == (startingMuxSel+0b0001)){

if(whichKeypad == 'L'){

midi.sendNoteOn(noteAddr2L, velocity);

}

else{

midi.sendNoteOn(noteAddr2R, velocity);

}

}

else if(i == (startingMuxSel+0b0010)){

if(whichKeypad == 'L'){

midi.sendNoteOn(noteAddr3L, velocity);

}

else{

midi.sendNoteOn(noteAddr3R, velocity);

}

}

else if(i == (startingMuxSel+0b0011)){

if(whichKeypad == 'L'){

midi.sendNoteOn(noteAddr4L, velocity);

}

else{

midi.sendNoteOn(noteAddr4R, velocity);

}

}

else if(i == (startingMuxSel+0b0100)){

if(whichKeypad == 'L'){

midi.sendNoteOn(noteAddr5L, velocity);

}

else{

midi.sendNoteOn(noteAddr5R, velocity);

}

}

else if(i == (startingMuxSel+0b0101)){

if(whichKeypad == 'L'){

midi.sendNoteOn(noteAddr6L, velocity);

}

else{

midi.sendNoteOn(noteAddr6R, velocity);

}

}

else if(i == (startingMuxSel+0b0110)){ //since B sharp dne, do not turn on in even zones

if(whichKeypad == 'L'){

midi.sendNoteOn(noteAddr7L, velocity);

}

else{

midi.sendNoteOn(noteAddr7R, velocity);

}

}

}

// Piano: Function to turn sendNoteOff depending on i

void chooseNoteOff(int i, char whichKeypad){

if(i == startingMuxSel){

if(whichKeypad == 'L'){

midi.sendNoteOff(noteAddr1L, velocity);

}

else{

midi.sendNoteOff(noteAddr1R, velocity);

}

}

else if(i == (startingMuxSel+0b0001)){

if(whichKeypad == 'L'){

midi.sendNoteOff(noteAddr2L, velocity);

}

else{

midi.sendNoteOff(noteAddr2R, velocity);

}

}

else if(i == (startingMuxSel+0b0010)){

if(whichKeypad == 'L'){

midi.sendNoteOff(noteAddr3L, velocity);

}

else{

midi.sendNoteOff(noteAddr3R, velocity);

}

}

else if(i == (startingMuxSel+0b0011)){

if(whichKeypad == 'L'){

midi.sendNoteOff(noteAddr4L, velocity);

}

else{

midi.sendNoteOff(noteAddr4R, velocity);

}

}

else if(i == (startingMuxSel+0b0100)){

if(whichKeypad == 'L'){

midi.sendNoteOff(noteAddr5L, velocity);

}

else{

midi.sendNoteOff(noteAddr5R, velocity);

}

}

else if(i == (startingMuxSel+0b0101)){

if(whichKeypad == 'L'){

midi.sendNoteOff(noteAddr6L, velocity);

}

else{

midi.sendNoteOff(noteAddr6R, velocity);

}

}

else if(i == (startingMuxSel+0b0110)){

if(whichKeypad == 'L'){

midi.sendNoteOff(noteAddr7L, velocity);

}

else{

midi.sendNoteOff(noteAddr7R, velocity);

}

}

}

// Function to eliminate noise on tiltSensor

int tiltSensorNoise(int8_t tiltSensor){

//Update tiltSensHist with tiltSensor by shifting items to the left

iteratetiltHist += 1;

if(iteratetiltHist >= 9){iteratetiltHist = 0; }

tiltSensHist[iteratetiltHist+1] = tiltSensHist[iteratetiltHist];

tiltSensHist[0] = tiltSensor;

cmpTilt = tiltSensor;

if(cmpTilt == tiltSensHist[iteratetiltHist]){

sameValCount++;

}

else{

secondTiltVal = tiltSensHist[iteratetiltHist];

}

if(sameValCount < 10 && (iteratetiltHist == 0)){ // if identical value is less than 5 update cmpTilt

cmpTilt = secondTiltVal;

}

return cmpTilt;

}

// Function assigns the appropriate struct to the for loop in the main depending on the i value

void pickStruct(int i){

if(i == (startingMuxSel)){

memcpy(&fsrStructL, &key1DataL, sizeof(key1DataL));

memcpy(&fsrStructR, &key1DataR, sizeof(key1DataR));

}

else if(i == (startingMuxSel+0b0001)){

memcpy(&fsrStructL, &key2DataL, sizeof(key2DataL));

memcpy(&fsrStructR, &key2DataR, sizeof(key2DataR));

}

else if(i == (startingMuxSel+0b0010)){

memcpy(&fsrStructL, &key3DataL, sizeof(key3DataL));

memcpy(&fsrStructR, &key3DataR, sizeof(key3DataR));

}

else if(i == (startingMuxSel+0b0011)){

memcpy(&fsrStructL, &key4DataL, sizeof(key4DataL));

memcpy(&fsrStructR, &key4DataR, sizeof(key4DataR));

}

else if(i == (startingMuxSel+0b0100)){

memcpy(&fsrStructL, &key5DataL, sizeof(key5DataL));

memcpy(&fsrStructR, &key5DataR, sizeof(key5DataR));

}

else if(i == (startingMuxSel+0b0101)){

memcpy(&fsrStructL, &key6DataL, sizeof(key6DataL));

memcpy(&fsrStructR, &key6DataR, sizeof(key6DataR));

}

else if(i == (startingMuxSel+0b0110)){

memcpy(&fsrStructL, &key7DataL, sizeof(key7DataL));

memcpy(&fsrStructR, &key7DataR, sizeof(key7DataR));

}

}

// Function copies all values from fsrStruct to key#Data

void copytoStruct(int i){

if(i == (startingMuxSel)){

memcpy(&key1DataL, &fsrStructL, sizeof(fsrStructL));

memcpy(&key1DataR, &fsrStructR, sizeof(fsrStructR));

}

else if(i == (startingMuxSel+0b0001)){

memcpy(&key2DataL, &fsrStructL, sizeof(fsrStructL));

memcpy(&key2DataR, &fsrStructR, sizeof(fsrStructR));

}

else if(i == (startingMuxSel+0b0010)){

memcpy(&key3DataL, &fsrStructL, sizeof(fsrStructL));

memcpy(&key3DataR, &fsrStructR, sizeof(fsrStructR));

}

else if(i == (startingMuxSel+0b0011)){

memcpy(&key4DataL, &fsrStructL, sizeof(fsrStructL));

memcpy(&key4DataR, &fsrStructR, sizeof(fsrStructR));

}

else if(i == (startingMuxSel+0b0100)){

memcpy(&key5DataL, &fsrStructL, sizeof(fsrStructL));

memcpy(&key5DataR, &fsrStructR, sizeof(fsrStructR));

}

else if(i == (startingMuxSel+0b0101)){

memcpy(&key6DataL, &fsrStructL, sizeof(fsrStructL));

memcpy(&key6DataR, &fsrStructR, sizeof(fsrStructR));

}

else if(i == (startingMuxSel+0b0110)){

memcpy(&key7DataL, &fsrStructL, sizeof(fsrStructL));

memcpy(&key7DataR, &fsrStructR, sizeof(fsrStructR));

}

}

// Piano: Function to determine appropriate notes keypad should produce dependent on value of rotary encoder

void setPianoNotes(int8_t tiltSensor, char whichKeypad){

int16_t rE_L = dataSigReceivedL.rotEncoder;

int16_t rE_R = dataSigReceivedR.rotEncoder;

if(whichKeypad == 'L'){

if(rE_L <= maxReRange){

//set note for fsr6 to C and fsr0 to F

noteAddr1L = {MIDI_Notes::E(2), Channel_1};

noteAddr2L = {41, Channel_1};

noteAddr5L = {MIDI_Notes::G(2), Channel_1};

noteAddr7L = {MIDI_Notes::A(2), Channel_1};

noteAddr3L = {MIDI_Notes::Eb(2), Channel_1};

noteAddr4L = {MIDI_Notes::Gb(2), Channel_1};

noteAddr6L = {MIDI_Notes::Ab(2), Channel_1};

//Serial.println("Zone 1");

}

else if(rE_L >= maxReRange+1 && rE_L <= 2*maxReRange){

//set note for fsr6 to C and fsr0 to F

noteAddr1L = {MIDI_Notes::B(2), Channel_1};

noteAddr2L = {MIDI_Notes::C(3), Channel_1};

noteAddr5L = {MIDI_Notes::D(3), Channel_1};

noteAddr7L = {MIDI_Notes::E(3), Channel_1};

noteAddr3L = {MIDI_Notes::Bb(2), Channel_1};

noteAddr4L = {MIDI_Notes::Db(3), Channel_1};

noteAddr6L = {MIDI_Notes::Eb(3), Channel_1};

//Serial.println("Zone 2");

}

else if(rE_L >= 2*maxReRange+1 && rE_L <= 3*maxReRange){

//set note for fsr6 to C and fsr0 to F

//MIDI_Notes::note ( int8_t note,int8_t numOctave ) ;

noteAddr1L = {53, Channel_1};

//noteAddr1L = {53, Channel_1};

noteAddr2L = {MIDI_Notes::G(3), Channel_1};

noteAddr5L = {MIDI_Notes::A(3), Channel_1};

noteAddr7L = {MIDI_Notes::B(3), Channel_1};

noteAddr3L = {MIDI_Notes::Gb(3), Channel_1};

noteAddr4L = {MIDI_Notes::Ab(3), Channel_1};

noteAddr6L = {MIDI_Notes::Bb(3), Channel_1};

//Serial.println("Zone 3");

}

else if(rE_L >= 3*maxReRange+1 && rE_L <= 4*maxReRange){

//set note for fsr6 to C and fsr0 to F

noteAddr1L = {MIDI_Notes::C(4), Channel_1};

noteAddr2L = {MIDI_Notes::D(4), Channel_1};

noteAddr5L = {MIDI_Notes::E(4), Channel_1};

noteAddr7L = {65, Channel_1};

noteAddr3L = {MIDI_Notes::Db(4), Channel_1};

noteAddr4L = {MIDI_Notes::Eb(4), Channel_1};

noteAddr6L = {MIDI_Notes::Gb(4), Channel_1};

//Serial.println("Zone 4");

}

else if(rE_L >= 4*maxReRange+1 && rE_L <= 5*maxReRange){

noteAddr1L = {MIDI_Notes::G(4), Channel_1};

noteAddr2L = {MIDI_Notes::A(4), Channel_1};

noteAddr5L = {MIDI_Notes::B(4), Channel_1};

noteAddr7L = {MIDI_Notes::C(5), Channel_1};

noteAddr3L = {MIDI_Notes::Ab(4), Channel_1};

noteAddr4L = {MIDI_Notes::Bb(4), Channel_1};

noteAddr6L = {MIDI_Notes::Db(5), Channel_1};

//Serial.println("Zone 5");

}

else if(rE_L >= 5*maxReRange+1){

noteAddr1L = {MIDI_Notes::D(5), Channel_1};

noteAddr2L = {MIDI_Notes::E(5), Channel_1};

noteAddr5L = {77, Channel_1};

noteAddr7L = {MIDI_Notes::G(5), Channel_1};

noteAddr3L = {MIDI_Notes::Eb(5), Channel_1};

noteAddr4L = {MIDI_Notes::Gb(5), Channel_1};

noteAddr6L = {MIDI_Notes::Ab(5), Channel_1};

//Serial.println("Zone 6");

}

}

else{

if(rE_R <= maxReRange){

noteAddr1R = {MIDI_Notes::D(5), Channel_1};

noteAddr3R = {MIDI_Notes::E(5), Channel_1};

noteAddr5R = {77, Channel_1};

noteAddr7R = {MIDI_Notes::G(5), Channel_1};

noteAddr2R = {MIDI_Notes::Eb(5), Channel_1};

noteAddr4R = {MIDI_Notes::Gb(5), Channel_1};

noteAddr6R = {MIDI_Notes::Ab(5), Channel_1};

//Serial.println("R: Zone 6");

}

else if(rE_R >= maxReRange+1 && rE_R <= 2*maxReRange){

noteAddr1R = {MIDI_Notes::G(4), Channel_1};

noteAddr3R = {MIDI_Notes::A(4), Channel_1};

noteAddr5R = {MIDI_Notes::B(4), Channel_1};

noteAddr7R = {MIDI_Notes::C(5), Channel_1};

noteAddr2R = {MIDI_Notes::Ab(4), Channel_1};

noteAddr4R = {MIDI_Notes::Bb(4), Channel_1};

noteAddr6R = {MIDI_Notes::Db(5), Channel_1};

//Serial.println("R: Zone 5");

}

else if(rE_R >= 2*maxReRange+1 && rE_R <= 3*maxReRange){

//set note for fsr6 to C and fsr0 to F

noteAddr1R = {MIDI_Notes::C(4), Channel_1};

noteAddr3R = {MIDI_Notes::D(4), Channel_1};

noteAddr5R = {MIDI_Notes::E(4), Channel_1};

noteAddr7R = {65, Channel_1};

noteAddr2R = {MIDI_Notes::Db(4), Channel_1};

noteAddr4R = {MIDI_Notes::Eb(4), Channel_1};

noteAddr6R = {MIDI_Notes::Gb(4), Channel_1};

//Serial.println("R: Zone 4");

}

else if(rE_R >= 3*maxReRange+1 && rE_R <= 4*maxReRange){

noteAddr1R = {53, Channel_1};

noteAddr3R = {MIDI_Notes::G(3), Channel_1};

noteAddr5R = {MIDI_Notes::A(3), Channel_1};

noteAddr7R = {MIDI_Notes::B(3), Channel_1};

noteAddr2R = {MIDI_Notes::Gb(3), Channel_1};

noteAddr4R = {MIDI_Notes::Ab(3), Channel_1};

noteAddr6R = {MIDI_Notes::Bb(3), Channel_1};

//Serial.println("R: Zone 3");

}

else if(rE_R >= 4*maxReRange+1 && rE_R <= 5*maxReRange){

//set note for fsr6 to C and fsr0 to F

noteAddr1R = {MIDI_Notes::B(2), Channel_1};

noteAddr3R = {MIDI_Notes::C(3), Channel_1};

noteAddr5R = {MIDI_Notes::D(3), Channel_1};

noteAddr7R = {MIDI_Notes::E(3), Channel_1};

noteAddr2R = {MIDI_Notes::Bb(2), Channel_1};

noteAddr4R = {MIDI_Notes::Db(3), Channel_1};

noteAddr6R = {MIDI_Notes::Eb(3), Channel_1};

//Serial.println("R: Zone 2");

}

else if(rE_R >= 5*maxReRange+1){

//set note for fsr6 to C and fsr0 to F

noteAddr1R = {MIDI_Notes::E(2), Channel_1};

noteAddr3R = {41, Channel_1};

noteAddr5R = {MIDI_Notes::G(2), Channel_1};

noteAddr7R = {MIDI_Notes::A(2), Channel_1};

noteAddr2R = {MIDI_Notes::Eb(2), Channel_1};

noteAddr4R= {MIDI_Notes::Gb(2), Channel_1};

noteAddr6R = {MIDI_Notes::Ab(2), Channel_1};

//Serial.println("R: Zone 1");

}

}

}

// Piano: Function turns piano on and off

void pianoMode(int i){

if(fsrStructL.prevVolume <= 24 && fsrStructL.currVolume <= 24 && fsrStructL.turnOffFirstTime == 1)

{

// make sure to only turn the previous note off

if(noteOnSig.ith_Val[i] == 1 && noteOnSig.whichKeypad[i] == 'L'){

chooseNoteOff(i,'L');

noteOnSig.ith_Val[i] = 0;

noteOnSig.whichKeypad[i] = 'N';

}

fsrStructL.turnOffFirstTime = 0;

fsrStructL.firstTimeNoteOn = 1;

}

else if(fsrStructL.currVolume >= 25 && fsrStructL.firstTimeNoteOn == 1){ //NOTE SHOULD ONLY GO OFF ONCE WHICH IS AT INITIAL TIME OF PRESS, after that it will never go here

fadeVolume(i, 'L');

fsrStructL.turnOffFirstTime = 1;

fsrStructL.firstTimeNoteOn = 0;

}

else{

//Serial.println("L: Do Nothing");

}

if(fsrStructR.prevVolume <= 24 && fsrStructR.currVolume <= 24 && fsrStructR.turnOffFirstTime == 1)

{

// make sure to only turn the previous note off

if(noteOnSig.ith_Val[i] == 1 && noteOnSig.whichKeypad[i] == 'R'){

chooseNoteOff(i, 'R');

noteOnSig.ith_Val[i] = 0;

noteOnSig.whichKeypad[i] = 'N';

}

fsrStructR.turnOffFirstTime = 0;

fsrStructR.firstTimeNoteOn = 1;

}

else if(fsrStructR.currVolume >= 25 && fsrStructR.firstTimeNoteOn == 1){ //NOTE SHOULD ONLY GO OFF ONCE WHICH IS AT INITIAL TIME OF PRESS, after that it will never go here

fadeVolume(i, 'R');

fsrStructR.turnOffFirstTime = 1;

fsrStructR.firstTimeNoteOn = 0;

}

else{

//Serial.println("R: Do Nothing");

}

}

// Piano: Function to set initial volume: if prev volume off, curr Volume on

void initializeVol(int channel){

if(channel == 1 || channel == 6 || channel == 5){

// Set Initial Volume

if(fsrStructL.prevVolume <= 24 && fsrStructL.currVolume >= 25){

fsrStructL.initVolume = fsrStructL.currVolume;

}

if(fsrStructR.prevVolume <= 24 && fsrStructR.currVolume >= 25){

fsrStructR.initVolume = fsrStructR.currVolume;

}

}

else if(channel == 2 || channel == 3 || channel == 4){//dataSigReceivedR.joystick >= 760 || dataSigReceivedR.joystick <= 280

if((fsrStructR.prevVolume <= JOYSTICKUPPERLIMIT && fsrStructR.prevVolume >= JOYSTICKLOWERLIMIT) && (fsrStructR.currVolume >= JOYSTICKUPPERLIMIT || fsrStructR.currVolume <= JOYSTICKLOWERLIMIT)){

fsrStructR.initVolume = fsrStructR.currVolume;

}

else{//initial vol stays exactly the same

}

}

}

// Piano: Function maps the values received to the volume range

int mapFSRtoVolume(int i, char whichKeypad){

//maps fsrValue(0-420) to somewhere in the volume range (0-127)

// constrain ensures that the value derived from map falls within the min and max which is 0 and 127

if(i == (startingMuxSel)){ //maps to mux channel 0(C0)

if(whichKeypad == 'L'){

return constrain(map(dataSigReceivedL.fsr0, 10, 290, 20, 127), 20, 127);

}

else{

return constrain(map(dataSigReceivedR.fsr0, 10, 250, 20, 127), 20, 127);

}

}

else if(i == (startingMuxSel+0b0001)){

if(whichKeypad == 'L'){

return constrain(map(dataSigReceivedL.fsr1, 10, 150, 20, 127), 20, 127);

}

else{

return constrain(map(dataSigReceivedR.fsr1, 10, 150, 20, 127), 20, 127);

}

}

else if(i == (startingMuxSel+0b0010)){

if(whichKeypad == 'L'){

return constrain(map(dataSigReceivedL.fsr2, 10, 200, 20, 127), 20, 127);

}

else{

return constrain(map(dataSigReceivedR.fsr2, 10, 300, 20, 127), 20, 127);

}

}

else if(i == (startingMuxSel+0b0011)){

if(whichKeypad == 'L'){

return constrain(map(dataSigReceivedL.fsr3, 10, 360, 20, 127), 20, 127);

}

else{

return constrain(map(dataSigReceivedR.fsr3, 10, 300, 20, 127), 20, 127);

}

}

else if(i == (startingMuxSel+0b0100)){

if(whichKeypad == 'L'){

return constrain(map(dataSigReceivedL.fsr4, 10, 90, 20, 127), 20, 127);

}

else{

return constrain(map(dataSigReceivedR.fsr4, 10, 200, 20, 127), 20, 127);

}

}

else if(i == (startingMuxSel+0b0101)){

if(whichKeypad == 'L'){

return constrain(map(dataSigReceivedL.fsr5, 10, 120, 20, 127), 20, 127);

}

else{

return constrain(map(dataSigReceivedR.fsr5, 10, 300, 20, 127), 20, 127);

}

}

else if(i == (startingMuxSel+0b0110)){

if(whichKeypad == 'L'){

return constrain(map(dataSigReceivedL.fsr6, 10, 140, 20, 127), 20, 127);

}

else{

return constrain(map(dataSigReceivedR.fsr6, 10, 200, 20, 127), 20, 127);

}

}

return 0;

}

// Sax: Function determines which note to turn on when in sax mode

void saxMode(){

bool keys[14];

keys[0] = (dataSigReceivedR.fsr0 >= 5) ? 1 : 0; //right keypad

keys[1] = (dataSigReceivedR.fsr2 >= 5) ? 1 : 0;

keys[2] = (dataSigReceivedR.fsr4 >= 5) ? 1 : 0;

keys[3] = (dataSigReceivedR.fsr6 >= 5) ? 1 : 0;

keys[4] = (dataSigReceivedR.fsr1 >= 5) ? 1 : 0;

keys[5] = (dataSigReceivedR.fsr3 >= 5) ? 1 : 0;

keys[6] = (dataSigReceivedR.fsr5 >= 5) ? 1 : 0;

keys[7] = (dataSigReceivedL.fsr0 >= 5) ? 1 : 0; //left keypad

keys[8] = (dataSigReceivedL.fsr1 >= 5) ? 1 : 0;

keys[9] = (dataSigReceivedL.fsr4 >= 5) ? 1 : 0;

keys[10] = (dataSigReceivedL.fsr6 >= 5) ? 1 : 0;

keys[11] = (dataSigReceivedL.fsr2 >= 5) ? 1 : 0;

keys[12] = (dataSigReceivedL.fsr3 >= 5) ? 1 : 0;

keys[13] = (dataSigReceivedL.fsr5 >= 5) ? 1 : 0;

Serial.println("Right Keys[]: "+String(keys[0])+","+String(keys[1])+","+String(keys[2])+","+String(keys[3])+","+String(keys[4])+","+String(keys[5])+","+String(keys[6]));

Serial.println("Left Keys[]: "+String(keys[7])+","+String(keys[8])+","+String(keys[9])+","+String(keys[10])+","+String(keys[11])+","+String(keys[12])+","+String(keys[13]));

//Serial.println("if condition result: "+String(keys[3] && keys[2] && keys[1] && keys[7] && keys[8] && keys[9]));

if(keys[3] && keys[2] && keys[1] && keys[7] && keys[8] && keys[9]){

//Bb3 to Eb4, D5 and Eb5

if(keys[13]){

//Bb3 to Db4

if(keys[0]){

saxNoteAddr = {MIDI_Notes::Bb(3), Channel_2};

}

else if(keys[4]){

saxNoteAddr = {MIDI_Notes::Db(4), Channel_2};

}

else{

saxNoteAddr = {MIDI_Notes::C(4), Channel_2};

}

}

else if(keys[10]){

//Eb4, Eb5

if(!keys[6]){

saxNoteAddr = {MIDI_Notes::Eb(4), Channel_2};

}

else{

saxNoteAddr = {MIDI_Notes::Eb(5), Channel_2};

}

}

else{

//D4,D5

if(!keys[6]){

saxNoteAddr = {MIDI_Notes::D(4), Channel_2};

}

else{

saxNoteAddr = {MIDI_Notes::D(5), Channel_2};

}

}

}

else if(keys[3] && keys[2] && keys[1] && keys[7] && keys[8] && !keys[9] && !keys[0] && !keys[10]){

//E4,E5

if(!keys[6]){

saxNoteAddr = {MIDI_Notes::E(4), Channel_2};

}

else{

saxNoteAddr = {MIDI_Notes::E(5), Channel_2};

}

}

else if(keys[3] && keys[2] && keys[1] && keys[7] && !keys[8] && !keys[9] ){

//F4,F5

if(!keys[6]){

saxNoteAddr = {65, Channel_2};

}

else{

saxNoteAddr = {77, Channel_2};

}

}

else if(keys[3] && keys[2] && keys[1] && !keys[7] && keys[8] && !keys[9]){

//Gb4,Gb5

if(!keys[6]){

saxNoteAddr = {MIDI_Notes::Gb(4), Channel_2};

}

else{

saxNoteAddr = {MIDI_Notes::Gb(5), Channel_2};

}

}

else if(keys[3] && keys[2] && keys[1] && !keys[7] && !keys[8] && !keys[9]){

//G4,Ab4,G5,Ab5

if(keys[0]){

if(keys[6]){

saxNoteAddr = {MIDI_Notes::Ab(5), Channel_2};

}

else{

saxNoteAddr = {MIDI_Notes::Ab(4), Channel_2};

}

}

else{

if(keys[6]){

saxNoteAddr = {MIDI_Notes::G(5), Channel_2};

}

else{

saxNoteAddr = {MIDI_Notes::G(4), Channel_2};

}

}

}

else if(keys[3] && keys[2] && !keys[1] && !keys[7] && !keys[8] && !keys[9]){

//A4,A5

if(!keys[6]){

saxNoteAddr = {MIDI_Notes::A(4), Channel_2};

}

else{

saxNoteAddr = {MIDI_Notes::A(5), Channel_2};

}

}

else if(keys[3] && !keys[2] && !keys[1] && !keys[7] && !keys[8] && !keys[9]){

//B4,B5

if(keys[6]){

if(keys[5]){

saxNoteAddr = {MIDI_Notes::Bb(5), Channel_2};

}

else{

saxNoteAddr = {MIDI_Notes::B(5), Channel_2};

}

}

else{

saxNoteAddr = {MIDI_Notes::B(4), Channel_2};

}

}

else if(!keys[3] && keys[2] && !keys[1] && !keys[7] && !keys[8] && !keys[9]){

//C5,C6

if(!keys[6]){

saxNoteAddr = {MIDI_Notes::C(5), Channel_2};

}

else{

saxNoteAddr = {MIDI_Notes::C(6), Channel_2};

}

}

else if(!keys[3] && !keys[2] && !keys[1] && !keys[7] && !keys[8] && !keys[9]){

//Db5,Db6

if(!keys[6]){

saxNoteAddr = {MIDI_Notes::Db(5), Channel_2};

}

else{

saxNoteAddr = {MIDI_Notes::Db(6), Channel_2};

}

}

//call function to send notes on/off

saxSendNotes();

}

// Sax: Function signals synthesizer to turn sax note w/ variable volume on when right joystick is pressed

void saxSendNotes(){

bool turnOff = ((fsrStructR.prevVolume <= JOYSTICKUPPERLIMIT && fsrStructR.prevVolume >= JOYSTICKLOWERLIMIT)&&(fsrStructR.currVolume <= JOYSTICKUPPERLIMIT && fsrStructR.currVolume >= JOYSTICKLOWERLIMIT)) ? 1:0;

bool turnOn = (fsrStructR.currVolume >= JOYSTICKUPPERLIMIT || fsrStructR.currVolume <= JOYSTICKLOWERLIMIT) ? 1:0;

if(turnOff && fsrStructR.turnOffFirstTime == 1){

//turn note off

midi.sendNoteOff(saxNoteAddr, velocity);

fsrStructR.turnOffFirstTime = 0;

fsrStructR.firstTimeNoteOn = 1;

}

else if(turnOn && fsrStructR.firstTimeNoteOn == 1){

int16_t mapped_joystick = 0;

if(dataSigReceivedR.joystick >= JOYSTICKUPPERLIMIT){

mapped_joystick = constrain(map(dataSigReceivedR.joystick, JOYSTICKUPPERLIMIT, 1023, 20, 127), 20, 127);

}

else{

mapped_joystick = constrain(map(dataSigReceivedR.joystick, JOYSTICKLOWERLIMIT, 0, 20, 127), 20, 127);

}

//Serial.println("Mapped Joystick: "+String(mapped_joystick));

midi.sendControlChange(ccAddr, mapped_joystick); //control volume then send note on

// Send pitch bend message

int pitchBendValue = map(dataSigReceivedL.joystick, 0, 1023, 0, 16383);

pitchBendValue = constrain(pitchBendValue, 0, 16383); // Ensure the value stays within bounds

midi.sendPitchBend(Channel_2, pitchBendValue);

midi.sendNoteOn(saxNoteAddr, velocity);

fsrStructR.turnOffFirstTime = 1;

fsrStructR.firstTimeNoteOn = 0;

}

}

// Clarinet: Function determines which note to turn on when in clarinet mode

void clarinetMode(){

bool keys[14];

keys[0] = (dataSigReceivedR.fsr0 >= 5) ? 1 : 0; //right keypad

keys[1] = (dataSigReceivedR.fsr2 >= 5) ? 1 : 0;

keys[2] = (dataSigReceivedR.fsr4 >= 5) ? 1 : 0;

keys[3] = (dataSigReceivedR.fsr6 >= 5) ? 1 : 0;

keys[4] = (dataSigReceivedR.fsr1 >= 5) ? 1 : 0;

keys[5] = (dataSigReceivedR.fsr3 >= 5) ? 1 : 0;

keys[6] = (dataSigReceivedR.fsr5 >= 5) ? 1 : 0;

keys[7] = (dataSigReceivedL.fsr0 >= 5) ? 1 : 0; //left keypad

keys[8] = (dataSigReceivedL.fsr1 >= 5) ? 1 : 0;

keys[9] = (dataSigReceivedL.fsr4 >= 5) ? 1 : 0;

keys[10] = (dataSigReceivedL.fsr6 >= 5) ? 1 : 0;

keys[11] = (dataSigReceivedL.fsr2 >= 5) ? 1 : 0;

keys[12] = (dataSigReceivedL.fsr3 >= 5) ? 1 : 0;

keys[13] = (dataSigReceivedL.fsr5 >= 5) ? 1 : 0;

Serial.println("Right Keys[]: "+String(keys[0])+","+String(keys[1])+","+String(keys[2])+","+String(keys[3])+","+String(keys[4])+","+String(keys[5])+","+String(keys[6]));

Serial.println("Left Keys[]: "+String(keys[7])+","+String(keys[8])+","+String(keys[9])+","+String(keys[10])+","+String(keys[11])+","+String(keys[12])+","+String(keys[13]));

// if statements to change clarinetNoteAddr

if(keys[3] && keys[2] && keys[1] && keys[7] && keys[8] && keys[9]){

if(!keys[10] && !keys[11] && !keys[12] && !keys[13] && !keys[5] && !keys[6] && keys[0]){

//G3

clarinetNoteAddr = {MIDI_Notes::G(3), Channel_3};

}

else if(!keys[10] && !keys[11] && keys[12] && !keys[13] && !keys[5] && !keys[6] && keys[0]){

//E3

clarinetNoteAddr = {MIDI_Notes::E(3), Channel_3};

}

else if(!keys[10] && !keys[11] && !keys[12] && keys[13] && !keys[5] && !keys[6] && keys[0]){

//F3

clarinetNoteAddr = {53, Channel_3};

}

else if(!keys[10] && keys[11] && !keys[12] && !keys[13] && !keys[5] && !keys[6] && keys[0]){

//Gb3

clarinetNoteAddr = {MIDI_Notes::Gb(3), Channel_3};

}

else if(!keys[10] && !keys[11] && keys[12] && !keys[13] && keys[5] && !keys[6] && keys[0]){

//B4

clarinetNoteAddr = {MIDI_Notes::B(4), Channel_3};

}

else if(!keys[10] && !keys[11] && !keys[12] && keys[13] && keys[5] && !keys[6] && keys[0]){

//C5

clarinetNoteAddr = {MIDI_Notes::C(5), Channel_3};

}

else if(keys[10] && !keys[11] && !keys[12] && !keys[13] && keys[5] && !keys[6] && keys[0]){

//Db5

clarinetNoteAddr = {MIDI_Notes::Db(5), Channel_3};

}

else if(!keys[10] && !keys[11] && !keys[12] && !keys[13] && keys[5] && !keys[6] && keys[0]){

//D5

clarinetNoteAddr = {MIDI_Notes::D(5), Channel_3};

}

else if(!keys[10] && keys[11] && !keys[12] && !keys[13] && keys[5] && !keys[6] && keys[0]){

//Eb5

clarinetNoteAddr = {MIDI_Notes::Eb(5), Channel_3};

}

}

else if(keys[3] && keys[2] && keys[1] && keys[7] && keys[8] && !keys[9]){

if(!keys[10] && !keys[11] && !keys[12] && !keys[13] && !keys[5] && !keys[6] && keys[0]){

//A3

clarinetNoteAddr = {MIDI_Notes::A(3), Channel_3};

}

else if(!keys[10] && !keys[11] && !keys[12] && !keys[13] && keys[5] && !keys[6] && keys[0]){

//E5

clarinetNoteAddr = {MIDI_Notes::E(5), Channel_3};

}

}

else if(keys[3] && keys[2] && keys[1] && keys[7] && !keys[8] && !keys[9]){

if(!keys[10] && !keys[11] && !keys[12] && !keys[13] && !keys[5] && !keys[6] && keys[0]){

//Bb3

clarinetNoteAddr = {MIDI_Notes::Bb(3), Channel_3};

}

else if(!keys[10] && !keys[11] && !keys[12] && !keys[13] && keys[5] && !keys[6] && keys[0]){

//F5

clarinetNoteAddr = {77, Channel_3};

}

}

else if(keys[3] && keys[2] && keys[1] && !keys[7] && keys[8] && !keys[9]){

if(!keys[10] && !keys[11] && !keys[12] && !keys[13] && !keys[5] && !keys[6] && keys[0]){

//B3

clarinetNoteAddr = {MIDI_Notes::B(3), Channel_3};

}

else if(!keys[10] && !keys[11] && !keys[12] && !keys[13] && keys[5] && !keys[6] && keys[0]){

//Gb5

clarinetNoteAddr = {MIDI_Notes::Gb(5), Channel_3};

}

}

else if(keys[3] && keys[2] && keys[1] && !keys[7] && !keys[8] && !keys[9]){

if(!keys[10] && !keys[11] && !keys[12] && !keys[13] && !keys[5] && !keys[6] && keys[0]){

//C4

clarinetNoteAddr = {MIDI_Notes::C(4), Channel_3};

}

else if(!keys[10] && !keys[11] && !keys[12] && !keys[13] && keys[5] && !keys[6] && keys[0]){

//G5

clarinetNoteAddr = {MIDI_Notes::G(5), Channel_3};

}

}

else if(keys[3] && keys[2] && !keys[1] && !keys[7] && !keys[8] && !keys[9]){

if(!keys[10] && !keys[11] && !keys[12] && !keys[13] && !keys[5] && !keys[6] && keys[0]){

//D4

clarinetNoteAddr = {MIDI_Notes::D(4), Channel_3};

}

else if(!keys[10] && !keys[11] && !keys[12] && !keys[13] && keys[5] && !keys[6] && keys[0]){

//A5

clarinetNoteAddr = {MIDI_Notes::A(5), Channel_3};

}

}

else if(keys[3] && !keys[2] && !keys[1]){

if(!keys[7] && !keys[8] && !keys[9] && !keys[10] && !keys[11] && !keys[12] && !keys[13] && !keys[5] && !keys[6] && keys[0]){

//E4

clarinetNoteAddr = {MIDI_Notes::E(4), Channel_3};

}

else if(keys[7] && !keys[8] && !keys[9] && !keys[10] && !keys[11] && !keys[12] && !keys[13] && !keys[5] && !keys[6] && keys[0]){

//Eb4

clarinetNoteAddr = {MIDI_Notes::Eb(4), Channel_3};

}

else if(!keys[7] && !keys[8] && !keys[9] && !keys[10] && !keys[11] && !keys[12] && !keys[13] && !keys[5] && !keys[6] && !keys[0]){

//Gb4

clarinetNoteAddr = {MIDI_Notes::Gb(4), Channel_3};

}

else if(keys[7] && !keys[8] && !keys[9] && !keys[10] && !keys[11] && !keys[12] && !keys[13] && keys[5] && !keys[6] && keys[0]){

//Bb5

clarinetNoteAddr = {MIDI_Notes::Bb(5), Channel_3};

}

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

//B5

clarinetNoteAddr = {MIDI_Notes::B(5), Channel_3};

}

}

else if(!keys[3] && !keys[2] && !keys[1] && !keys[7] && !keys[8] && !keys[9]){

if(!keys[10] && !keys[11] && !keys[12] && !keys[13] && !keys[5] && keys[6] && !keys[0]){

//A4

clarinetNoteAddr = {MIDI_Notes::A(4), Channel_3};

}

else if(!keys[10] && !keys[11] && !keys[12] && !keys[13] && keys[5] && keys[6] && !keys[0]){

//Bb4

clarinetNoteAddr = {MIDI_Notes::Bb(4), Channel_3};

}

else if(!keys[10] && !keys[11] && !keys[12] && !keys[13] && !keys[5] && !keys[6] && keys[0]){

//F4

clarinetNoteAddr = {65, Channel_3};

}

else if(!keys[10] && !keys[11] && !keys[12] && !keys[13] && keys[5] && !keys[6] && keys[0]){

//C6

clarinetNoteAddr = {MIDI_Notes::C(6), Channel_3};

}

}

else if(!keys[3] && keys[2] && keys[1] && keys[7] && keys[8] && !keys[9]){

if(!keys[10] && !keys[11] && !keys[12] && !keys[13] && keys[5] && !keys[6] && keys[0]){

//Db6

clarinetNoteAddr = {MIDI_Notes::Db(6), Channel_3};

}

}

else if(!keys[3] && keys[2] && keys[1] && keys[7] && !keys[8] && !keys[9]){

//D6

clarinetNoteAddr = {MIDI_Notes::D(6), Channel_3};

}

else if(!keys[3] && keys[2] && keys[1] && !keys[7] && !keys[8] && !keys[9]){

//E6

clarinetNoteAddr = {MIDI_Notes::E(6), Channel_3};

}

else if(!keys[3] && !keys[2] && !keys[1] && !keys[7] && !keys[8] && !keys[9]){

//G4

clarinetNoteAddr = {MIDI_Notes::G(4), Channel_3};

}

//call function to send notes on/off

clarinetSendNotes();

}

// Clarinet: Function signals synthesizer to turn clarinet note w/ variable volume on when right joystick is pressed

void clarinetSendNotes(){

bool turnOff = ((fsrStructR.prevVolume <= JOYSTICKUPPERLIMIT && fsrStructR.prevVolume >= JOYSTICKLOWERLIMIT)&&(fsrStructR.currVolume <= JOYSTICKUPPERLIMIT && fsrStructR.currVolume >= JOYSTICKLOWERLIMIT)) ? 1:0;

bool turnOn = (fsrStructR.currVolume >= JOYSTICKUPPERLIMIT || fsrStructR.currVolume <= JOYSTICKLOWERLIMIT) ? 1:0;

if(turnOff && fsrStructR.turnOffFirstTime == 1){

//turn note off

midi.sendNoteOff(clarinetNoteAddr, velocity);

fsrStructR.turnOffFirstTime = 0;

fsrStructR.firstTimeNoteOn = 1;

}

else if(turnOn && fsrStructR.firstTimeNoteOn == 1){

int16_t mapped_joystick = 0;

if(dataSigReceivedR.joystick >= JOYSTICKUPPERLIMIT){

mapped_joystick = constrain(map(dataSigReceivedR.joystick, JOYSTICKUPPERLIMIT, 1023, 20, 127), 20, 127);

}

else{

mapped_joystick = constrain(map(dataSigReceivedR.joystick, JOYSTICKLOWERLIMIT, 0, 20, 127), 20, 127);

}

Serial.println("Mapped Joystick: "+String(mapped_joystick));

midi.sendControlChange(ccAddr, mapped_joystick); //control volume then send note on

// Send pitch bend message

int pitchBendValue = map(dataSigReceivedL.joystick, 0, 1023, 0, 16383);

pitchBendValue = constrain(pitchBendValue, 0, 16383); // Ensure the value stays within bounds

midi.sendPitchBend(Channel_3, pitchBendValue);

midi.sendNoteOn(clarinetNoteAddr, velocity);

fsrStructR.turnOffFirstTime = 1;

fsrStructR.firstTimeNoteOn = 0;

}

}

// Flute: Function determines which note to turn on when in flute mode

void fluteMode(){

bool keys[14];

keys[0] = (dataSigReceivedR.fsr0 >= 5) ? 1 : 0; //right keypad

keys[1] = (dataSigReceivedR.fsr2 >= 5) ? 1 : 0;

keys[2] = (dataSigReceivedR.fsr4 >= 5) ? 1 : 0;

keys[3] = (dataSigReceivedR.fsr6 >= 5) ? 1 : 0;

keys[4] = (dataSigReceivedR.fsr1 >= 5) ? 1 : 0;

keys[5] = (dataSigReceivedR.fsr3 >= 5) ? 1 : 0;

keys[6] = (dataSigReceivedR.fsr5 >= 5) ? 1 : 0;

keys[7] = (dataSigReceivedL.fsr0 >= 5) ? 1 : 0; //left keypad

keys[8] = (dataSigReceivedL.fsr1 >= 5) ? 1 : 0;

keys[9] = (dataSigReceivedL.fsr4 >= 5) ? 1 : 0;

keys[10] = (dataSigReceivedL.fsr6 >= 5) ? 1 : 0;

keys[11] = (dataSigReceivedL.fsr2 >= 5) ? 1 : 0;

keys[12] = (dataSigReceivedL.fsr3 >= 5) ? 1 : 0;

keys[13] = (dataSigReceivedL.fsr5 >= 5) ? 1 : 0;

Serial.println("Left Keys[]: "+String(keys[7])+","+String(keys[8])+","+String(keys[9])+","+String(keys[10])+","+String(keys[11])+","+String(keys[12])+","+String(keys[13]));

Serial.println("Right Keys[]: "+String(keys[0])+","+String(keys[1])+","+String(keys[2])+","+String(keys[3])+","+String(keys[4])+","+String(keys[5])+","+String(keys[6]));

// if statements to change fluteNoteAddr

if(keys[3] && keys[2] && keys[1] && keys[7] && keys[8] && keys[9]){

if(!keys[10] && !keys[11] && !keys[12] && !keys[13] && !keys[5] && !keys[6] && keys[0]){

//G3

fluteNoteAddr = {MIDI_Notes::G(3), Channel_4};

}

else if(!keys[10] && !keys[11] && keys[12] && !keys[13] && !keys[5] && !keys[6] && keys[0]){

//E3

fluteNoteAddr = {MIDI_Notes::E(3), Channel_4};

}

else if(!keys[10] && !keys[11] && !keys[12] && keys[13] && !keys[5] && !keys[6] && keys[0]){

//F3

fluteNoteAddr = {53, Channel_4};

}

else if(!keys[10] && keys[11] && !keys[12] && !keys[13] && !keys[5] && !keys[6] && keys[0]){

//Gb3

fluteNoteAddr = {MIDI_Notes::Gb(3), Channel_4};

}

else if(!keys[10] && !keys[11] && keys[12] && !keys[13] && keys[5] && !keys[6] && keys[0]){

//B4

fluteNoteAddr = {MIDI_Notes::B(4), Channel_4};

}

else if(!keys[10] && !keys[11] && !keys[12] && keys[13] && keys[5] && !keys[6] && keys[0]){

//C5

fluteNoteAddr = {MIDI_Notes::C(5), Channel_4};

}

else if(keys[10] && !keys[11] && !keys[12] && !keys[13] && keys[5] && !keys[6] && keys[0]){

//Db5

fluteNoteAddr = {MIDI_Notes::Db(5), Channel_4};

}

else if(!keys[10] && !keys[11] && !keys[12] && !keys[13] && keys[5] && !keys[6] && keys[0]){

//D5

fluteNoteAddr = {MIDI_Notes::D(5), Channel_4};

}

else if(!keys[10] && keys[11] && !keys[12] && !keys[13] && keys[5] && !keys[6] && keys[0]){

//Eb5

fluteNoteAddr = {MIDI_Notes::Eb(5), Channel_4};

}

}

else if(keys[3] && keys[2] && keys[1] && keys[7] && keys[8] && !keys[9]){

if(!keys[10] && !keys[11] && !keys[12] && !keys[13] && !keys[5] && !keys[6] && keys[0]){

//A3

fluteNoteAddr = {MIDI_Notes::A(3), Channel_4};

}

else if(!keys[10] && !keys[11] && !keys[12] && !keys[13] && keys[5] && !keys[6] && keys[0]){

//E5

fluteNoteAddr = {MIDI_Notes::E(5), Channel_4};

}

}

else if(keys[3] && keys[2] && keys[1] && keys[7] && !keys[8] && !keys[9]){

if(!keys[10] && !keys[11] && !keys[12] && !keys[13] && !keys[5] && !keys[6] && keys[0]){

//Bb3

fluteNoteAddr = {MIDI_Notes::Bb(3), Channel_4};

}

else if(!keys[10] && !keys[11] && !keys[12] && !keys[13] && keys[5] && !keys[6] && keys[0]){

//F5

fluteNoteAddr = {77, Channel_4};

}

}

else if(keys[3] && keys[2] && keys[1] && !keys[7] && keys[8] && !keys[9]){

if(!keys[10] && !keys[11] && !keys[12] && !keys[13] && !keys[5] && !keys[6] && keys[0]){

//B3

fluteNoteAddr = {MIDI_Notes::B(3), Channel_4};

}

else if(!keys[10] && !keys[11] && !keys[12] && !keys[13] && keys[5] && !keys[6] && keys[0]){

//Gb5

fluteNoteAddr = {MIDI_Notes::Gb(5), Channel_4};

}

}

else if(keys[3] && keys[2] && keys[1] && !keys[7] && !keys[8] && !keys[9]){

if(!keys[10] && !keys[11] && !keys[12] && !keys[13] && !keys[5] && !keys[6] && keys[0]){

//C4

fluteNoteAddr = {MIDI_Notes::C(4), Channel_4};

}

else if(!keys[10] && !keys[11] && !keys[12] && !keys[13] && keys[5] && !keys[6] && keys[0]){

//G5

fluteNoteAddr = {MIDI_Notes::G(5), Channel_4};

}

}

else if(keys[3] && keys[2] && !keys[1] && !keys[7] && !keys[8] && !keys[9]){

if(!keys[10] && !keys[11] && !keys[12] && !keys[13] && !keys[5] && !keys[6] && keys[0]){

//D4

fluteNoteAddr = {MIDI_Notes::D(4), Channel_4};

}

else if(!keys[10] && !keys[11] && !keys[12] && !keys[13] && keys[5] && !keys[6] && keys[0]){

//A5

fluteNoteAddr = {MIDI_Notes::A(5), Channel_4};

}

}

else if(keys[3] && !keys[2] && !keys[1]){

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

//E4

fluteNoteAddr = {MIDI_Notes::E(4), Channel_4};

}

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

//Eb4

fluteNoteAddr = {MIDI_Notes::Eb(4), Channel_4};

}

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

//Gb4

fluteNoteAddr = {MIDI_Notes::Gb(4), Channel_4};

}

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

//Bb5

fluteNoteAddr = {MIDI_Notes::Bb(5), Channel_4};

}

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

//B5

fluteNoteAddr = {MIDI_Notes::B(5), Channel_4};

}

}

else if(!keys[3] && !keys[2] && !keys[1] && !keys[7] && !keys[8] && !keys[9]){

if(!keys[10] && !keys[11] && !keys[12] && !keys[13] && !keys[5] && keys[6] && !keys[0]){

//A4

fluteNoteAddr = {MIDI_Notes::A(4), Channel_4};

}

else if(!keys[10] && !keys[11] && !keys[12] && !keys[13] && keys[5] && keys[6] && !keys[0]){

//Bb4

fluteNoteAddr = {MIDI_Notes::Bb(4), Channel_4};

}

else if(!keys[10] && !keys[11] && !keys[12] && !keys[13] && !keys[5] && !keys[6] && keys[0]){

//F4

fluteNoteAddr = {65, Channel_4};

}

else if(!keys[10] && !keys[11] && !keys[12] && !keys[13] && keys[5] && !keys[6] && keys[0]){

//C6

fluteNoteAddr = {MIDI_Notes::C(6), Channel_4};

}

}

else if(!keys[3] && keys[2] && keys[1] && keys[7] && keys[8] && !keys[9]){

if(!keys[10] && !keys[11] && !keys[12] && !keys[13] && keys[5] && !keys[6] && keys[0]){

//Db6

fluteNoteAddr = {MIDI_Notes::Db(6), Channel_4};

}

}

else if(!keys[3] && keys[2] && keys[1] && keys[7] && !keys[8] && !keys[9]){

//D6

fluteNoteAddr = {MIDI_Notes::D(6), Channel_4};

}

else if(!keys[3] && keys[2] && keys[1] && !keys[7] && !keys[8] && !keys[9]){

//E6

fluteNoteAddr = {MIDI_Notes::E(6), Channel_4};

}

else if(!keys[3] && !keys[2] && !keys[1] && !keys[7] && !keys[8] && !keys[9]){

//G4

fluteNoteAddr = {MIDI_Notes::G(4), Channel_4};

}

//call function to send notes on/off

fluteSendNotes();

}

// Flute: Function signals synthesizer to turn flute note w/ variable volume on when right joystick is pressed

void fluteSendNotes(){

bool turnOff = ((fsrStructR.prevVolume <= JOYSTICKUPPERLIMIT && fsrStructR.prevVolume >= JOYSTICKLOWERLIMIT)&&(fsrStructR.currVolume <= JOYSTICKUPPERLIMIT && fsrStructR.currVolume >= JOYSTICKLOWERLIMIT)) ? 1:0;

bool turnOn = (fsrStructR.currVolume >= JOYSTICKUPPERLIMIT || fsrStructR.currVolume <= JOYSTICKLOWERLIMIT) ? 1:0;

if(turnOff && fsrStructR.turnOffFirstTime == 1){

//turn note off

midi.sendNoteOff(fluteNoteAddr, velocity);

fsrStructR.turnOffFirstTime = 0;

fsrStructR.firstTimeNoteOn = 1;

}

else if(turnOn && fsrStructR.firstTimeNoteOn == 1){

int16_t mapped_joystick = 0;

if(dataSigReceivedR.joystick >= JOYSTICKUPPERLIMIT){

mapped_joystick = constrain(map(dataSigReceivedR.joystick, JOYSTICKUPPERLIMIT, 1023, 20, 127), 20, 127);

}

else{

mapped_joystick = constrain(map(dataSigReceivedR.joystick, JOYSTICKLOWERLIMIT, 0, 20, 127), 20, 127);

}

Serial.println("Mapped Joystick: "+String(mapped_joystick));

midi.sendControlChange(ccAddr, mapped_joystick); //control volume then send note on

// Send pitch bend message

int pitchBendValue = map(dataSigReceivedL.joystick, 0, 1023, 0, 16383);

pitchBendValue = constrain(pitchBendValue, 0, 16383); // Ensure the value stays within bounds

midi.sendPitchBend(Channel_4, pitchBendValue);

midi.sendNoteOn(fluteNoteAddr, velocity);

fsrStructR.turnOffFirstTime = 1;

fsrStructR.firstTimeNoteOn = 0;

}

}

// Bass Guitar: Function determines which note to send

void setBassNotes(){

int16_t rE_R = dataSigReceivedR.rotEncoder;

// if zone1 then set notes for right keypad noteAddr1R-noteAddr4R values

bool zone1 = (rE_R <= maxReRange) ? 1 : 0;

bool zone2 = (rE_R >= maxReRange+1 && rE_R <= 2*maxReRange) ? 1 : 0;

bool zone3 = (rE_R >= 2*maxReRange+1 && rE_R <= 3*maxReRange) ? 1 : 0;

bool zone4 = (rE_R >= 3*maxReRange+1 && rE_R <= 4*maxReRange) ? 1 : 0;

if(zone1){ //top of the rod

noteAddr1R = {65, Channel_6};

noteAddr3R = {MIDI_Notes::Bb(4), Channel_6};

noteAddr5R = {MIDI_Notes::Eb(4), Channel_6};

noteAddr7R = {MIDI_Notes::Ab(4), Channel_6};

}

else if(zone2){

noteAddr1R = {MIDI_Notes::Gb(4), Channel_6};

noteAddr3R = {MIDI_Notes::B(4), Channel_6};

noteAddr5R = {MIDI_Notes::E(4), Channel_6};

noteAddr7R = {MIDI_Notes::A(4), Channel_6};

}

else if(zone3){

noteAddr1R = {MIDI_Notes::G(4), Channel_6};

noteAddr3R = {MIDI_Notes::C(4), Channel_6};

noteAddr5R = {77, Channel_6};

noteAddr7R = {MIDI_Notes::Bb(5), Channel_6};

}

else if(zone4){

noteAddr1R = {MIDI_Notes::Ab(5), Channel_6};

noteAddr3R = {MIDI_Notes::Db(5), Channel_6};

noteAddr5R = {MIDI_Notes::Gb(5), Channel_6};

noteAddr7R = {MIDI_Notes::B(5), Channel_6};

}

else{

noteAddr1R = {MIDI_Notes::A(5), Channel_6};

noteAddr3R = {MIDI_Notes::D(5), Channel_6};

noteAddr5R = {MIDI_Notes::G(5), Channel_6};

noteAddr7R = {MIDI_Notes::C(5), Channel_6};

}

//Serial.println("Bass Guitar Notes Set");

}

// Bass Guitar

void bassFadeVolume(int ith_Val){

// Pitch Bend

int pitchBendValue = map(dataSigReceivedL.joystick, 0, 1023, 0, 16383);

pitchBendValue = constrain(pitchBendValue, 0, 16383);

midi.sendPitchBend(Channel_6, pitchBendValue);

if(fsrStructR.initVolume > fsrStructR.currVolume){

//decrease volume very fast

for(int i=fsrStructR.initVolume; i>=0; i-=10)

{

midi.sendControlChange(ccAddr, fsrStructR.initVolume); //changes CC to volume control option

// would be sending the prev. volume

chooseNoteOn(ith_Val, 'R');

}

}

else{

// decrease volume slowly

for(int i=fsrStructR.initVolume; i>=0; i-=5)

{

midi.sendControlChange(ccAddr, fsrStructR.initVolume); //changes CC to volume control option

// would be sending the prev. volume

chooseNoteOn(ith_Val, 'R');

}

}

//update noteOnHis struct here

noteOnSig.ith_Val[ith_Val] = 1;

noteOnSig.whichKeypad[ith_Val] = 'R';

}

// Bass Guitar: Function determines which note is turned on or off

void bassGuitarMode(int i){

if(fsrStructR.prevVolume <= 24 && fsrStructR.currVolume <= 24 && fsrStructR.turnOffFirstTime == 1)

{

//Serial.println("Bass Guitar Note Off");

// make sure to only turn the previous note off

if(noteOnSig.ith_Val[i] == 1 && noteOnSig.whichKeypad[i] == 'R'){

chooseNoteOff(i,'R');

noteOnSig.ith_Val[i] = 0;

noteOnSig.whichKeypad[i] = 'N';

}

fsrStructR.turnOffFirstTime = 0;

fsrStructR.firstTimeNoteOn = 1;

}

else if(fsrStructR.currVolume >= 25 && fsrStructR.firstTimeNoteOn == 1){ //NOTE SHOULD ONLY GO OFF ONCE WHICH IS AT INITIAL TIME OF PRESS, after that it will never go here

//Serial.println("Bass Guitar Note On");

bassFadeVolume(i);

fsrStructR.turnOffFirstTime = 1;

fsrStructR.firstTimeNoteOn = 0;

}

else{

//Serial.println("Bass Guitar Skips");

}

}

// Chinese Piano

void setCPianoNotes(int8_t tiltSensor, char whichKeypad){

int16_t rE_L = dataSigReceivedL.rotEncoder;

int16_t rE_R = dataSigReceivedR.rotEncoder;

if(whichKeypad == 'L'){

if(rE_L <= maxReRange){

//set note for fsr6 to C and fsr0 to F

noteAddr1L = {MIDI_Notes::E(2), Channel_5};

noteAddr2L = {41, Channel_5};

noteAddr5L = {MIDI_Notes::G(2), Channel_5};

noteAddr7L = {MIDI_Notes::A(2), Channel_5};

noteAddr3L = {MIDI_Notes::Eb(2), Channel_5};

noteAddr4L = {MIDI_Notes::Gb(2), Channel_5};

noteAddr6L = {MIDI_Notes::Ab(2), Channel_5};

//Serial.println("Zone 1");

}

else if(rE_L >= maxReRange+1 && rE_L <= 2*maxReRange){

//set note for fsr6 to C and fsr0 to F

noteAddr1L = {MIDI_Notes::B(2), Channel_5};

noteAddr2L = {MIDI_Notes::C(3), Channel_5};

noteAddr5L = {MIDI_Notes::D(3), Channel_5};

noteAddr7L = {MIDI_Notes::E(3), Channel_5};

noteAddr3L = {MIDI_Notes::Bb(2), Channel_5};

noteAddr4L = {MIDI_Notes::Db(3), Channel_5};

noteAddr6L = {MIDI_Notes::Eb(3), Channel_5};

//Serial.println("Zone 2");

}

else if(rE_L >= 2*maxReRange+1 && rE_L <= 3*maxReRange){

//set note for fsr6 to C and fsr0 to F

//MIDI_Notes::note ( int8_t note,int8_t numOctave ) ;

noteAddr1L = {53, Channel_5};

//noteAddr1L = {53, Channel_5};

noteAddr2L = {MIDI_Notes::G(3), Channel_5};

noteAddr5L = {MIDI_Notes::A(3), Channel_5};

noteAddr7L = {MIDI_Notes::B(3), Channel_5};

noteAddr3L = {MIDI_Notes::Gb(3), Channel_5};

noteAddr4L = {MIDI_Notes::Ab(3), Channel_5};

noteAddr6L = {MIDI_Notes::Bb(3), Channel_5};

//Serial.println("Zone 3");

}

else if(rE_L >= 3*maxReRange+1 && rE_L <= 4*maxReRange){

//set note for fsr6 to C and fsr0 to F

noteAddr1L = {MIDI_Notes::C(4), Channel_5};

noteAddr2L = {MIDI_Notes::D(4), Channel_5};

noteAddr5L = {MIDI_Notes::E(4), Channel_5};

noteAddr7L = {65, Channel_5};

noteAddr3L = {MIDI_Notes::Db(4), Channel_5};

noteAddr4L = {MIDI_Notes::Eb(4), Channel_5};

noteAddr6L = {MIDI_Notes::Gb(4), Channel_5};

//Serial.println("Zone 4");

}

else if(rE_L >= 4*maxReRange+1 && rE_L <= 5*maxReRange){

noteAddr1L = {MIDI_Notes::G(4), Channel_5};

noteAddr2L = {MIDI_Notes::A(4), Channel_5};

noteAddr5L = {MIDI_Notes::B(4), Channel_5};

noteAddr7L = {MIDI_Notes::C(5), Channel_5};

noteAddr3L = {MIDI_Notes::Ab(4), Channel_5};

noteAddr4L = {MIDI_Notes::Bb(4), Channel_5};

noteAddr6L = {MIDI_Notes::Db(5), Channel_5};

//Serial.println("Zone 5");

}

else if(rE_L >= 5*maxReRange+1){

noteAddr1L = {MIDI_Notes::D(5), Channel_5};

noteAddr2L = {MIDI_Notes::E(5), Channel_5};

noteAddr5L = {77, Channel_5};

noteAddr7L = {MIDI_Notes::G(5), Channel_5};

noteAddr3L = {MIDI_Notes::Eb(5), Channel_5};

noteAddr4L = {MIDI_Notes::Gb(5), Channel_5};

noteAddr6L = {MIDI_Notes::Ab(5), Channel_5};

//Serial.println("Zone 6");

}

}

else{

if(rE_R <= maxReRange){

noteAddr1R = {MIDI_Notes::D(5), Channel_5};

noteAddr3R = {MIDI_Notes::E(5), Channel_5};

noteAddr5R = {77, Channel_5};

noteAddr7R = {MIDI_Notes::G(5), Channel_5};

noteAddr2R = {MIDI_Notes::Eb(5), Channel_5};

noteAddr4R = {MIDI_Notes::Gb(5), Channel_5};

noteAddr6R = {MIDI_Notes::Ab(5), Channel_5};

//Serial.println("R: Zone 6");

}

else if(rE_R >= maxReRange+1 && rE_R <= 2*maxReRange){

noteAddr1R = {MIDI_Notes::G(4), Channel_5};

noteAddr3R = {MIDI_Notes::A(4), Channel_5};

noteAddr5R = {MIDI_Notes::B(4), Channel_5};

noteAddr7R = {MIDI_Notes::C(5), Channel_5};

noteAddr2R = {MIDI_Notes::Ab(4), Channel_5};

noteAddr4R = {MIDI_Notes::Bb(4), Channel_5};

noteAddr6R = {MIDI_Notes::Db(5), Channel_5};

//Serial.println("R: Zone 5");

}

else if(rE_R >= 2*maxReRange+1 && rE_R <= 3*maxReRange){

//set note for fsr6 to C and fsr0 to F

noteAddr1R = {MIDI_Notes::C(4), Channel_5};

noteAddr3R = {MIDI_Notes::D(4), Channel_5};

noteAddr5R = {MIDI_Notes::E(4), Channel_5};

noteAddr7R = {65, Channel_5};

noteAddr2R = {MIDI_Notes::Db(4), Channel_5};

noteAddr4R = {MIDI_Notes::Eb(4), Channel_5};

noteAddr6R = {MIDI_Notes::Gb(4), Channel_5};

//Serial.println("R: Zone 4");

}

else if(rE_R >= 3*maxReRange+1 && rE_R <= 4*maxReRange){

noteAddr1R = {53, Channel_5};

noteAddr3R = {MIDI_Notes::G(3), Channel_5};

noteAddr5R = {MIDI_Notes::A(3), Channel_5};

noteAddr7R = {MIDI_Notes::B(3), Channel_5};

noteAddr2R = {MIDI_Notes::Gb(3), Channel_5};

noteAddr4R = {MIDI_Notes::Ab(3), Channel_5};

noteAddr6R = {MIDI_Notes::Bb(3), Channel_5};

//Serial.println("R: Zone 3");

}

else if(rE_R >= 4*maxReRange+1 && rE_R <= 5*maxReRange){

//set note for fsr6 to C and fsr0 to F

noteAddr1R = {MIDI_Notes::B(2), Channel_5};

noteAddr3R = {MIDI_Notes::C(3), Channel_5};

noteAddr5R = {MIDI_Notes::D(3), Channel_5};

noteAddr7R = {MIDI_Notes::E(3), Channel_5};

noteAddr2R = {MIDI_Notes::Bb(2), Channel_5};

noteAddr4R = {MIDI_Notes::Db(3), Channel_5};

noteAddr6R = {MIDI_Notes::Eb(3), Channel_5};

//Serial.println("R: Zone 2");

}

else if(rE_R >= 5*maxReRange+1){

//set note for fsr6 to C and fsr0 to F

noteAddr1R = {MIDI_Notes::E(2), Channel_5};

noteAddr3R = {41, Channel_5};

noteAddr5R = {MIDI_Notes::G(2), Channel_5};

noteAddr7R = {MIDI_Notes::A(2), Channel_5};

noteAddr2R = {MIDI_Notes::Eb(2), Channel_5};

noteAddr4R= {MIDI_Notes::Gb(2), Channel_5};

noteAddr6R = {MIDI_Notes::Ab(2), Channel_5};

//Serial.println("R: Zone 1");

}

}

}

// Piano: Function to produce key fade in piano mode

void cPianoFadeVolume(int ith_Val, char whichKeypad){

// Pitch Bend

int pitchBendValue = map(dataSigReceivedL.joystick, 0, 1023, 0, 16383);

pitchBendValue = constrain(pitchBendValue, 0, 16383);

midi.sendPitchBend(Channel_5, pitchBendValue);

// manipulate the velocity for this

// decrease faster if the velocity by a lot if the initial pressure is greater than following pressure

// decrease slowly if the initial pressure is equal to, a little bit greater than or less than following pressure

if(whichKeypad == 'L'){

if(fsrStructL.initVolume > fsrStructL.currVolume){

//decrease volume very fast

for(int i=fsrStructL.initVolume; i>=0; i-=10)

{

midi.sendControlChange(ccAddr, fsrStructL.initVolume); //changes CC to volume control option

// would be sending the prev. volume

chooseNoteOn(ith_Val, 'L');

}

}

else{

// decrease volume slowly

for(int i=fsrStructL.initVolume; i>=0; i-=5)

{

midi.sendControlChange(ccAddr, fsrStructL.initVolume); //changes CC to volume control option

// would be sending the prev. volume

chooseNoteOn(ith_Val, 'L');

}

}

}

else{

if(fsrStructR.initVolume > fsrStructR.currVolume){

//decrease volume very fast

for(int i=fsrStructR.initVolume; i>=0; i-=10)

{

midi.sendControlChange(ccAddr, fsrStructR.initVolume); //changes CC to volume control option

// would be sending the prev. volume

chooseNoteOn(ith_Val, 'R');

}

}

else{

// decrease volume slowly

for(int i=fsrStructR.initVolume; i>=0; i-=5)

{

midi.sendControlChange(ccAddr, fsrStructR.initVolume); //changes CC to volume control option

// would be sending the prev. volume

chooseNoteOn(ith_Val, 'R');

}

}

}

//update noteOnHis struct here

noteOnSig.ith_Val[ith_Val] = 1;

noteOnSig.whichKeypad[ith_Val] = whichKeypad;

}

// Chinese Piano

void chinesePianoMode(int i){

if(fsrStructL.prevVolume <= 24 && fsrStructL.currVolume <= 24 && fsrStructL.turnOffFirstTime == 1)

{

// make sure to only turn the previous note off

if(noteOnSig.ith_Val[i] == 1 && noteOnSig.whichKeypad[i] == 'L'){

chooseNoteOff(i,'L');

noteOnSig.ith_Val[i] = 0;

noteOnSig.whichKeypad[i] = 'N';

}

fsrStructL.turnOffFirstTime = 0;

fsrStructL.firstTimeNoteOn = 1;

}

else if(fsrStructL.currVolume >= 25 && fsrStructL.firstTimeNoteOn == 1){ //NOTE SHOULD ONLY GO OFF ONCE WHICH IS AT INITIAL TIME OF PRESS, after that it will never go here

cPianoFadeVolume(i, 'L');

fsrStructL.turnOffFirstTime = 1;

fsrStructL.firstTimeNoteOn = 0;

}

else{

//Serial.println("L: Do Nothing");

}

if(fsrStructR.prevVolume <= 24 && fsrStructR.currVolume <= 24 && fsrStructR.turnOffFirstTime == 1)

{

// make sure to only turn the previous note off

if(noteOnSig.ith_Val[i] == 1 && noteOnSig.whichKeypad[i] == 'R'){

chooseNoteOff(i, 'R');

noteOnSig.ith_Val[i] = 0;

noteOnSig.whichKeypad[i] = 'N';

}

fsrStructR.turnOffFirstTime = 0;

fsrStructR.firstTimeNoteOn = 1;

}

else if(fsrStructR.currVolume >= 25 && fsrStructR.firstTimeNoteOn == 1){ //NOTE SHOULD ONLY GO OFF ONCE WHICH IS AT INITIAL TIME OF PRESS, after that it will never go here

cPianoFadeVolume(i, 'R');

fsrStructR.turnOffFirstTime = 1;

fsrStructR.firstTimeNoteOn = 0;

}

else{

//Serial.println("R: Do Nothing");

}

}

// Final Demo Function///////////////////////////////////////////////////////////////////////////////////////////

int switchInstruments(int8_t tiltSensor, int16_t rE_L){

char tilt = 'A';

int8_t rotPlate_L = (dataSigReceivedL.rotPlate1<<2) | (dataSigReceivedL.rotPlate2<<1) | dataSigReceivedL.rotPlate3; //left rotation Plate

//update history of rotPlate

if(rotPlate_L != 0b111){

rotPlateHist[0] = rotPlateHist[1];

rotPlateHist[1] = rotPlate_L;

}

//Serial.println("s tiltSensor: "+String(tiltSensor));

Serial.println("Left Rotational Plate: "+String(rotPlate_L));

//determine orientation of tilt sensor

if(tiltSensor == 0b011 || tiltSensor == 0b110 || tiltSensor == 0b001){

tilt = 'V';

}

else if(tiltSensor == 0b101){

tilt = 'A';

}

else{

tilt = 'H';

}

//Serial.println("Tilt Sensor: "+String(tiltSensor));

Serial.println("Rotational Plate: "+String(rotPlateHist[1]));

if(tilt == 'H'){

if(rotPlateHist[1] == 0b101){

//channel 1 to piano

return 1;

}

else if(rotPlateHist[1] == 0b011){

//channel 4 to flute

return 4;

}

else if(rotPlateHist[1] == 0b110){

//channel 5 to Chinese Piano

return 5;

}

}

else if(tilt == 'A'){

if(dataSigReceivedR.rotEncoder < borderValue_L){

//channel 2 to sax

return 2;

}

else if(dataSigReceivedR.rotEncoder >= borderValue_L){

//channel 3 to clarinet

return 3;

}

}

else if(tilt == 'V'){

//channel 6 to bass guitar

return 6;

}

return 1;

}

void setup(void){

Serial.begin(9600);

pinMode(sensorHPin, INPUT);

pinMode(sensorVPin, INPUT);

pinMode(sensorAPin, INPUT);

radio.begin(); // Start the NRF24L01

radio.openReadingPipe(1, 0xABCDEF12); //left keypad Tx

radio.openReadingPipe(2, 0xABCDEF23); //right keypad Tx

radio.setPALevel(RF24_PA_LOW);

radio.startListening();

midi.begin(); //Initializes MIDI interface

Serial.println("-------------------------Program Start------------------------");

}

void loop(void){

//read in values for tiltSensor

int sensor_HValue = digitalRead(sensorHPin);

int sensor_VValue = digitalRead(sensorVPin);

int sensor_AValue = digitalRead(sensorAPin);

int8_t tiltSensor = (sensor_HValue << 2) | (sensor_VValue << 1) | sensor_AValue;

tiltSensorNoise(tiltSensor);

Serial.println("Tilt Sensor: "+String(tiltSensor));

if(radio.available()){

radio.read(&tempSig, sizeof(tempSig));

//if left or right is 0, then copy all values from tempSig to dataSigReceivedL, else dataSigReceivedR

if(tempSig.lOrR == 0){

memcpy(&dataSigReceivedL, &tempSig, sizeof(tempSig));

}

else{

memcpy(&dataSigReceivedR, &tempSig, sizeof(tempSig));

}

for(int8_t i=startingMuxSel; i<=(startingMuxSel + 0b0110); i++){

pickStruct(i); //copy dataSigReceived to temp struct

int16_t rE_L = dataSigReceivedL.rotEncoder;

//only needs to be called once since both keypads should be on the same channel

int which_channel = switchInstruments(tiltSensor, rE_L);

if(which_channel == 1){

Serial.println("Piano Mode On");

fsrStructL.prevVolume = fsrStructL.currVolume;

fsrStructR.prevVolume = fsrStructR.currVolume;

fsrStructL.currVolume = mapFSRtoVolume(i, 'L');

fsrStructR.currVolume = mapFSRtoVolume(i, 'R');

// initalize volume: fsrStuct(L/R).initVolume;

initializeVol(which_channel);

// set notes to keys here and return a zone to prevent B sharp from turning on

setPianoNotes(cmpTilt, 'L');

setPianoNotes(cmpTilt, 'R');

// Pitch Bend

int pitchBendValue = map(dataSigReceivedL.joystick, 0, 1023, 0, 16383);

pitchBendValue = constrain(pitchBendValue, 0, 16383);

midi.sendPitchBend(Channel_1, pitchBendValue);

// if note is released or just not pressed, then proceed, else turn note on

pianoMode(i);

}

else if(which_channel == 2){

Serial.println("Saxophone Mode On");

//maintain volume history

fsrStructR.prevVolume = fsrStructR.currVolume;

fsrStructR.currVolume = dataSigReceivedR.joystick;

initializeVol(which_channel);

//call function for sax...

saxMode();

}

else if(which_channel == 3){

Serial.println("Clarinet Mode On");

//maintain volume history

fsrStructR.prevVolume = fsrStructR.currVolume;

fsrStructR.currVolume = dataSigReceivedR.joystick;

initializeVol(which_channel);

//call function for clarinet...

clarinetMode();

}

else if(which_channel == 4){

Serial.println("Flute Mode On");

//maintain volume history

fsrStructR.prevVolume = fsrStructR.currVolume;

fsrStructR.currVolume = dataSigReceivedR.joystick;

initializeVol(which_channel);

//call function for flute...

fluteMode();

}

else if(which_channel == 5){

Serial.println("Chinese Piano Mode On");

//call function for chinese piano...

fsrStructL.prevVolume = fsrStructL.currVolume;

fsrStructR.prevVolume = fsrStructR.currVolume;

fsrStructL.currVolume = mapFSRtoVolume(i, 'L');

fsrStructR.currVolume = mapFSRtoVolume(i, 'R');

// initalize volume: fsrStuct(L/R).initVolume;

initializeVol(which_channel);

// set notes to keys here and return a zone to prevent B sharp from turning on

setCPianoNotes(cmpTilt, 'L');

setCPianoNotes(cmpTilt, 'R');

// if note is released or just not pressed, then proceed, else turn note on

chinesePianoMode(i);

}

else if(which_channel == 6){

Serial.println("Bass Guitar Mode On");

//maintain volume history

fsrStructR.prevVolume = fsrStructR.currVolume;

fsrStructR.currVolume = mapFSRtoVolume(i, 'R');

initializeVol(which_channel);

//call function for bass guitar...

setBassNotes();

bassGuitarMode(i);

}

//call function to copy all values from fsrReading(L/R) to struct

copytoStruct(i);

}

Serial.println("");

Serial.println("dataSigReceivedL: "+String(dataSigReceivedL.fsr0)+", "+String(dataSigReceivedL.fsr1)+", "+String(dataSigReceivedL.fsr2)+", "+String(dataSigReceivedL.fsr3)+", "+String(dataSigReceivedL.fsr4)+", "+String(dataSigReceivedL.fsr5)+", "+String(dataSigReceivedL.fsr6));

Serial.println("dataSigReceivedR: "+String(dataSigReceivedR.fsr0)+", "+String(dataSigReceivedR.fsr1)+", "+String(dataSigReceivedR.fsr2)+", "+String(dataSigReceivedR.fsr3)+", "+String(dataSigReceivedR.fsr4)+", "+String(dataSigReceivedR.fsr5)+", "+String(dataSigReceivedR.fsr6));

Serial.println("Joystick(Left/Right): "+String(dataSigReceivedL.joystick)+","+String(dataSigReceivedR.joystick));

Serial.println("Rotary Encoder(Left/Right): "+String(dataSigReceivedL.rotEncoder)+","+String(dataSigReceivedR.rotEncoder));

}

else

{

Serial.println("No msg received ");

}

midi.update(); // Handle or discard MIDI input

delay(23);

}
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

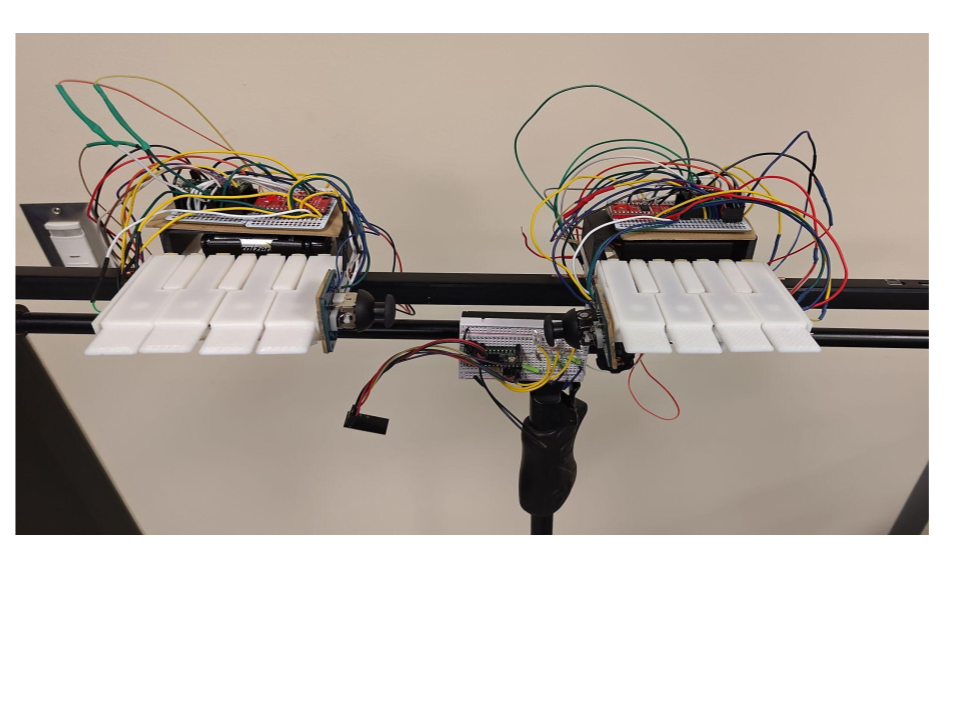
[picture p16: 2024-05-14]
images/Entire Design.png

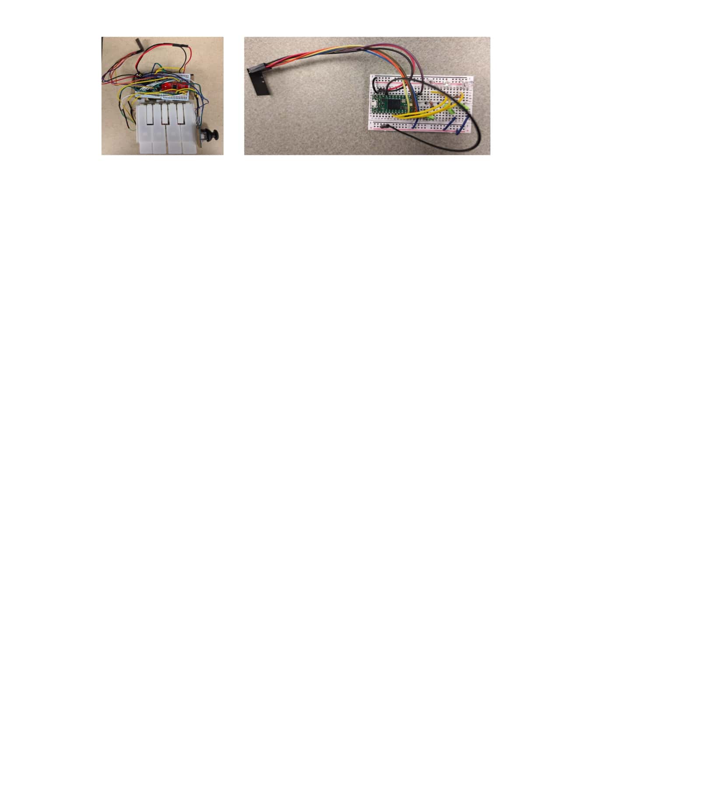
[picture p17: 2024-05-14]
images/Keypad and Base Station.jpg

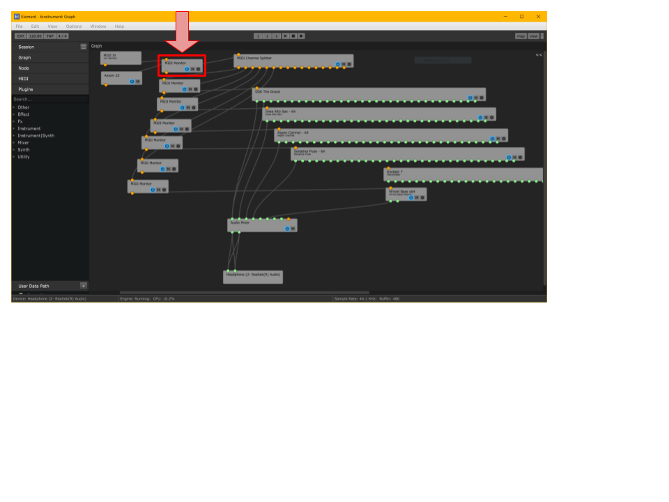
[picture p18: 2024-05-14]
images/Synthesizer Pic.png

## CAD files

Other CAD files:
CAD Designs/Battery_Bracket.f3d
CAD Designs/BlackKey.f3d
CAD Designs/NEW+Key+Housing.f3d
CAD Designs/WhiteKeyCLRNew.f3d
CAD Designs/WhiteKeyLRNew.f3d
CAD Designs/base+plate+radial.f3d
CAD Designs/keypad+spacer.f3d
CAD Designs/printable+top+piece.f3d
CAD Designs/rail+proto-type-3x+gear.f3d
CAD Designs/rail+proto-type-3x.f3d
CAD Designs/rotart+encoder+wheel.f3d
CAD Designs/rotary+encoder+holder+plate.f3d
CAD Designs/screw+washer.f3d
CAD Designs/space+4mm.f3d
CAD Designs/spacer+2mm.f3d

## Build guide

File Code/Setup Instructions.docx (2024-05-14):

To ensure the proper setup of the Arduino IDE, follow these steps and install the necessary libraries and plugins:

1. Libraries Installation:
  - Control Surface Library (https://tttapa.github.io/Control-Surface-doc/Doxygen/d8/da8/md_pages_Installation.html)by tttapa
  - Joystick (https://github.com/gmarty2000-ARDUINO/arduino-JOYSTICK)by Giuseppe Martini
  - RF24 (https://www.arduino.cc/reference/en/libraries/rf24/)by TMRh20
  - light_CD74HC4067 (https://www.arduino.cc/reference/en/libraries/light_cd74hc4067/)by SunitRaut
  - Encoder (https://www.arduino.cc/reference/en/libraries/encoder/)by Paul Stoffregen
  - SPI
2. Code Upload:
  - Upload the code from FinalTest_TxL to the left keypad.
  - Upload the code from FinalTest_TxR to the right keypad.
  - Upload the code from FinalTest_Rx to the base station.
3. Plugin and Synthesizer Setup:
  - Download all plugins from the provided plugin folder.
  - Download the synthesizer program "Kushview Element. (https://kushview.net/element/download/)"
  - Open NovelMIDISynth.els from the Synthesizer Plugins & Session Folder in Element.
4. Synthesizer Configuration:
  - In Element, navigate to File > Preferences > MIDI and select "Control Surface Library" if not already chosen.
  - Exit the preferences screen and double-click on the MIDI Monitor as shown in Figure i below.

By following these steps, you'll have the necessary components installed, codes uploaded, and synthesizer configured for your project.

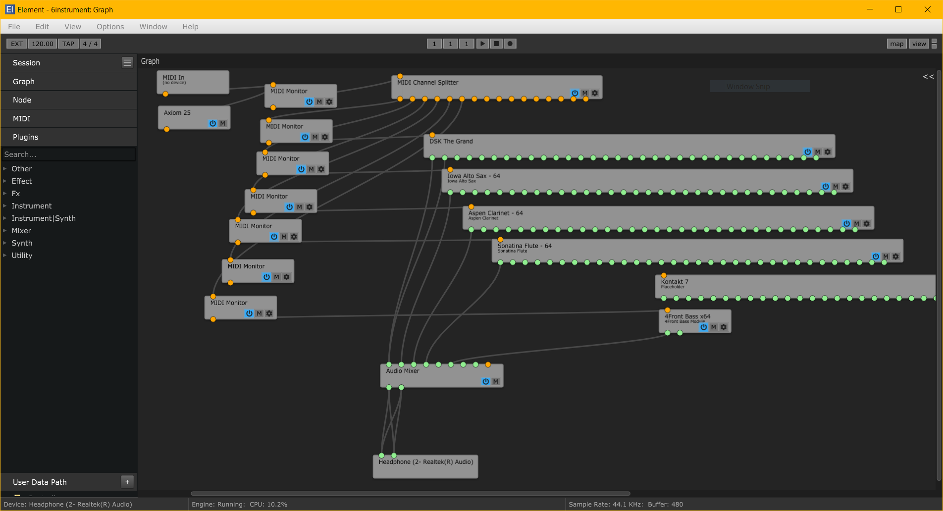
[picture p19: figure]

Figure i. The image above shows the connections for all plugins within the synthesizer program.

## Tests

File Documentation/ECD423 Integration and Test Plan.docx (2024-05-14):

ECD423 Novel MIDI Instrument

ECD Integration and Test Plan

# 1 Scope

## 1.1 System Overview

This document details the integration and test plan for the project. Successful system verification should demonstrate that the ECD 423 Novel MIDI Instrument is in full compliance with its Project Specification to all key stakeholders.

The purpose of this project is to create a Novel MIDI Instrument that is capable of polyphony, variable volume control and pitch bend. Our design is a detachable metal rail with 2 sliding keypads, a tilt detection system and a base station which is attachable to the lifting tube of the mic stand. The base station sends signals to the synthesizer via USB port. The device is capable of being attached to a tripod boom mic stand without inhibiting the mic stand's original functionality. The user is able to play a variety of MIDI instruments on the device. Keypad rotation, keypad location on the rail and tilting of the rail is taken into account in order to switch between different instruments. The user is able to control the type of notes being produced by the synthesizer using keys on the keypad as well as location of the keypad on the rail. Sliding the keypads up and down the rod can produce note changes depending on what instrument is being played. A joystick attachment to the side of each keypad is controlled by the user’s thumb and can be used to produce pitch bend.

## 1.2 Document Overview

This test plan describes the test site(s) and test environment(s) to be used in Section 3 and the tests in Section 4, followed by the detailed test procedures in Section 5.

In this document, a mandatory practice is identified by “shall”, a good practice by “should”, permission by “may” or “can”, expected outcome or action by “will”, and descriptive material by “is” or “are” (or another verb form of “to be”).

# 2 Referenced Documents

The following documents are referenced and inform part of this document. The table of Finalized Derived Requirements which was finalized in the Project Specification document, included in Appendix A of the Final Report is also included in this document in Appendix A.

      1 ECD 423 Novel MIDI Instrument Final Report
      2 ECD 423 Novel MIDI Instrument Project Specification

# 3 Integration and Test Environment

## 3.1 Seymour Kunis Media Core

The primary site for the tests outlined in this document is the Seymour Kunis Media Core room, situated in the Engineering and Science building at the Innovative Technologies Complex. The selection of this room was influenced in part by the endorsement of the team's advisor, Dr. Scott Craver, and also because it is equipped with all the essential tools required for constructing and testing the project, including synthesizers, 3D printers, and previous MIDI projects.

### 3.1.1 Hardware and Firmware Items

The list below reveals the hardware components and applications used during the testing stage to demonstrate completion of design requirements.

Testing Equipment

1. 3D Printer: The majority of components in this project will be 3D printed due to its flexibility in creating different shapes and sizes for the keypad. This device will be used continuously during the design process to determine and optimize the dimensions of the keypad components..
2. Multimeter: This device is used to measure the current/voltage of specific components that are connected on the breadboard. It is used to locate errors within circuitry and to aid in creating solutions for these problems.
3. Oscilloscope: This is used for similar reasons as the multimeter as it generates visual representations of voltage signals over time which can display the strength of the wireless communicator over specific distances.
4. Power Supply: The keypads will need a constant flow of 3.3V to power each keypad in order to maintain regular functions. A strong power source is crucial to implementing any tests that involve operating the keypads.
5. Weights: In order to test and calibrate the force sensitive resistors, small weights will be put on the key to apply the constant force which should be interpreted relatively the same on each force sensitive resistor.

Project Equipment

6. Keypad Enclosure: This device will be tested to show a number of requirements for this project. The first being how accurate the data, which is user pressure, is reflected based on the change in volume in the Synthesizer. The second being the ability of the system to determine in what rotated state the keypads are in at any given time. The third is to check whether the lamello-like keys are able to operate like piano keys. Finally, the response time test will utilize this hardware component to determine time taken from the user pressing on a key to a MIDI sound being produced.
7. Tilt Detection System: This system is a separate part of the project intended to detect 3 different states that the mic stand will be in at any point in time. There will be a test specifically conducted to prove this function by attaching LEDs in series with each tilt switch and using a protractor to determine the range of angles which correspond to each state (horizontal, vertical, and angled).
8. Rotary Encoder: This piece will be built-in to the lower segment of the keypad and will be used to determine the distance of each keypad from the center of the mic stand at any given point in time. Through the rotary encoder Test, the device will be tested for accuracy in calculating relative position when the user moves the keypad along the rail.
9. nRF24L01: This is a wireless transceiver/receiver module whose purpose in this project is to provide wireless communication between the keypad and the base station (Arduino Nano/Teensy to the Teensy 4.0). It relays information unidirectionally by acting as a bridge to relay user input from the keypad to trigger corresponding sounds from the synthesizer.
10. Laptop: Laptops will be used to program Arduinos and read the serial monitor off arduino. The laptop will also be used to host the element program to which the arduino will connect to via usb.
11. Force Sensitive Resistors: In order to measure the press of a key, a force sensitive resistor will be used. when connected to an arduino it will give an 8 bit value of pressure exerted.
12. Joystick: This is an add-on piece to the side of the keypads and will be used to control pitch bend. moving the stick up or down will change the pitch of the note. This will be used in the Joystick Test which will look for the ability to control pitch bend.

### 3.1.2 Software Items

The list below reveals the software components and applications used during the testing stage to demonstrate completion of design requirements.

1. Autodesk Fusion 360: This application is used to produce CAD designs such as the keys on the keypad, housing design, and sliders which attach the keypad to the metal rod.
2. Element (Synthesizer): This software application is the final destination for the MIDI signal. It is what produces the particular note that the user would like to hear. User data is produced and processed through Arduino Nano’s/Teensy’s to the Teensy 4.0 wirelessly which then gets converted into usable MIDI signals to the synthesizer.
3. Arduino IDE: This is a code editor to connect with Arduino hardware and give it specific instructions. The entire software application of this project relies heavily on this interface by programming Arduino microcontrollers with code that allows them to convert information to usable data.
4. RF24 Library: This library was installed onto the Arduino IDE for the purposes of this project. It has built in functions which are used to establish communication between the transceiver and receiver(nRF24L01) and transmit signals in one direction, from the Arduino Nano/Teensy to the Teensy 4.0.
5. Control Surface Library: Similar to the RF24, this library was also installed for this project for its pre-existing functions. These functions are implemented by the Teensy 4.0 and sent to the synthesizer such that it can trigger specific notes, generate pitch bend and perform variable volume control.
6. File demo1_MidiTest: This file contains the Arduino code to send MIDI signals from the base station microcontroller to the synthesizer. It contains a set of for loops to demonstrate the playing of notes, pitch bend, variable volume control and changing of instruments.
7. Files demo2_distanceTestTx and demo2_distanceTestRx: This file contains code written in Arduino IDE to continuously send a fixed message from the transceiver to the receiver. It will be used in the wireless distance test to determine whether the distance between wireless communication is met.
8. File demo3_multipleTransceiver: This file contains code written in Arduino IDE to continuously send messages between 2+ transceivers uni-directionally towards one receiver. It is a test of the quality of the message as well as the speed at which the message is being transmitted.
9. File demo4_KeypadOrientation: This code contains serial print messages to tell the tester what orientation the mic stand is based on the tilt detection system. It is to be used when the microcontroller is being connected to the circuitry with the tilt sensors and will display the horizontal, vertical, or angled orientation. In addition, the relative position of the rotary encoder and the rotation of the keypad is displayed here as well. The instrument that the mic stand is switched to depending on the orientation of these 3 factors is also printed out.
10. Input Files: A collection of .ino files which are used to program onto the microcontrollers in this project through Arduino IDE. These files are used to set up connections between hardware components to accurately process data.
11. Keypad Program: This program that will run on the keypad microcontrollers This program will get all the data from the various sensors on the keypad and pack them into easily transmittable messages.
12. Base Station Program: This is the program that will run on the base station microcontroller. This program will receive the messages from the keypads and then use that to create a midi message and send it to the laptop.

### 3.1.3 Other Materials

No Other Materials except the materials stated above will be needed for the tests.

### 3.1.4 Participants

Tests will be conducted at the Media Core lab by the members of the ECD 423 Project.

### 3.1.5 Tests To Be Performed

1. MIDI Test: This test will focus on sending MIDI messages from the Base Station to a synthesizer called Element. It will be conducted with a Teensy 4.0 connected over USB to a synthesizer program. The Teensy will be programmed to send specific MIDI messages to the computer and the MIDI monitor on the synthesizer program will be checked to determine whether the correct MIDI notes are being emitted along with the correct pitch bend and volume.
2. Wireless Communication Distance Test: This evaluation will be performed to determine whether the connection distance between transceiver and receiver modules is reliable enough to prevent disconnect. Also, there should be a transmittable distance of at least 50 inches.
3. Multiple Transceivers Communication Test: The purpose of this evaluation is to demonstrate the ability to perform uni-directional communication by 2 transceivers and 1 receiver module. The quality/frequency of successful transmissions will be taken into account as well.
4. Tilt Sensor Test: This test will test to see if the tilt sensors can accurately measure the 3 positions of tilt (vertical, horizontal and slanted) while the device is in use.
5. Rotary Encoder Test: This test will be used to determine how accurate the rotary encoder can measure the relative position of the keypad on the rod. It will be conducted by moving a rotary encoder with a wheel attachment along the rail. The rotary encoder will be connected to an Arduino Nano/Teensy to record measurements obtained from the encoder.
6. Keypad Rotation Test: This test will ensure that both keypads are able to detect the 4 positions of rotation, which include 0^o ,90^o ,180^o , and 270^o .
7. Instrument Transition Test: This test will determine if the instrument can accurately detect all of the different instruments that the user is attempting to play.
8. Variable Volume Test: This test focuses on the amount of force the Force Sensitive Resistors (FSR) can read from the keypresses. This test will be performed by applying forces to the key with an FSR underneath and it can reliably detect 10 different levels of force which will correspond to volume percentage. The keys will be hooked up to an analog multiplexer which will be controlled and read by an Arduino Nano/Teensy.
9. Lamellophone Key Test: This test will determine if the lamellophone key can operate a force sensitive resistor. It will consist of the lamellophone portion being plucked and whether the FSR can reliably detect 10 different levels of force in this mode.
10. Joystick Test: This test will be performed to check that the joystick can be read and translated into a pitch bend message. The test will consist of a two-axis joystick being connected to an Arduino Nano/Teensy and that the Nano/Teensy can reliably read the output of the two-axis joystick.
11. Final Test: This is an evaluation on the product as a whole. It will involve playing a tune on the MIDI mic stand to demonstrate its usability. The user will also demonstrate switching between different instruments.

# 4 System Integration

## 4.1 System Integration Diagram

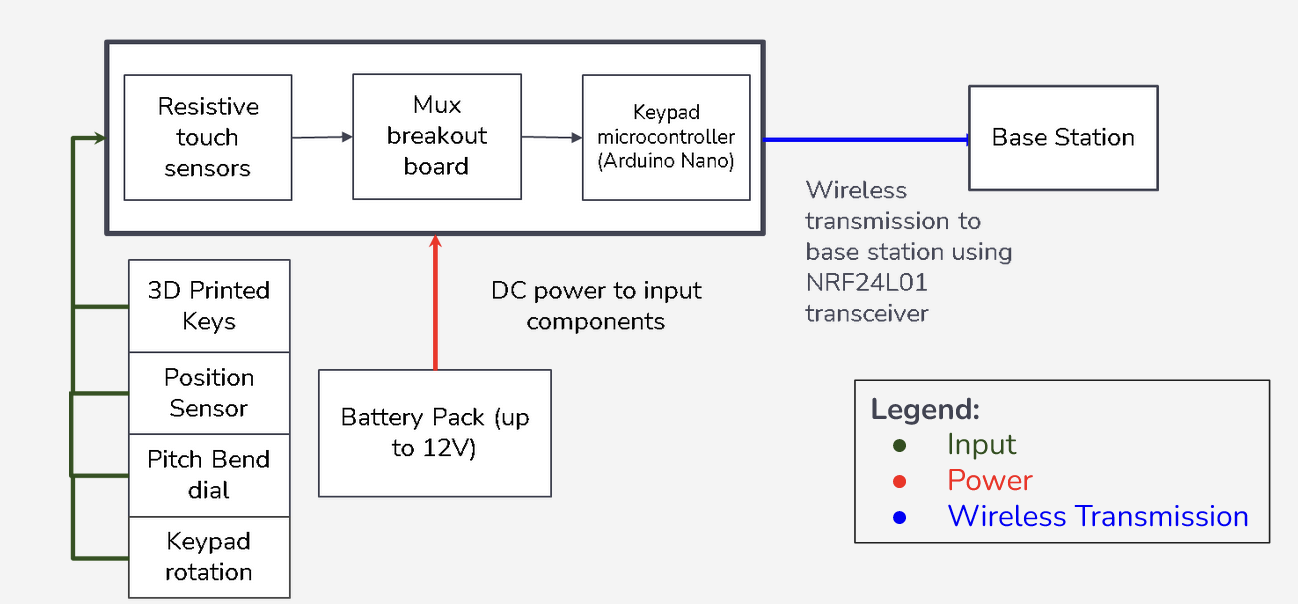
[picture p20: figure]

Figure 1. Diagram detailing the keypad input

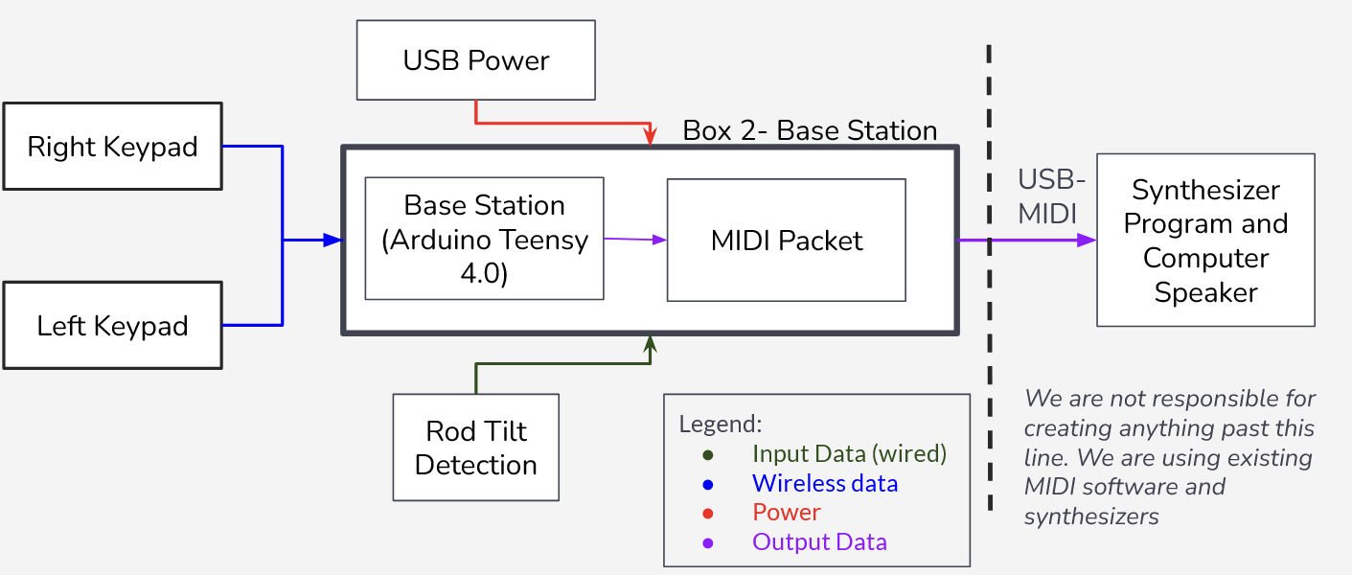
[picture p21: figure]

Figure 2: Diagram detailing the operation of the base station

## 4.2 User Input and Circuit

The user input is taken from a set of 7 keys on each keypad. Beneath each of the keys is a force-sensitive resistor (FSR). By pressing the key harder or softer, the user is able to control the volume of the MIDI output signal. All the FSRs in each keypad are connected to a multiplexer (MUX) breakout board, which allows multiple signals to be connected to the input pins on the Arduino board. In this way, the number of input pins can be greatly reduced and encoded into a smaller number of output pins.

## 4.3 Circuits and Software

The multiplexer circuit and the Arduino Nano/Teensy in the keypads will be configured in such a way where one pin on the Arduino accepts the input and outputs it from another pin to the nRF24L01 wireless transmitter. The wireless transmitter sends this data to the Arduino Teensy 4.0 board inside the base station, as detailed above.

## 4.4 MIDI Software

Once the multiplexed signals are received by the base station, they must be converted, along with the pitch bend data from the joystick on the side of the keypad to a MIDI signal. Once synthesized, the MIDI packet is sent to the open-source synthesizer software Element, where it can be processed and outputted.

  4.5 Output

After being processed in the Element software, the synthesized MIDI packet can be output over a set of computer speakers, at which point the project requirements are satisfied.

# 5 System Verification

These qualification methods will be used in verifying that the project system meets all requirements in its Project Specification.

- Demonstration (D)
- Test (T)
- Analysis (A)
- Inspection (I)

The following Requirement Categories (RC) are used to describe the purpose of each test:

- System Capability Requirements (SC)
- System External Interface Requirements (EI)
- Project Business Requirements (PB)
- Other Requirements (O)

## 5.1 Verification Overview

The table displayed below shows all of the tests to be performed as proof of meeting all design requirements mentioned in the project specifications document. The name of the test is provided along with their Test ID, details regarding the requirement being fulfilled and test completion date. Please note that test completion dates which display times that have yet to arrive are simply estimated dates and not the actual time of completion.

## 5.2 Test Coverage

Test ID | Test Name | QM | RC | Requirements Addressed | Test Completion Date
ECD423-T-001 | MIDI Test | I,D,T | O,EI,SC | ECD423-R-001 ECD423-R-002 ECD423-R-003 ECD423-R-004 ECD423-R-011 | 2023-11-13
ECD423-T-002 | Wireless Communication Distance Test | I | O,SC | ECD423-R-004 ECD423-R-008 | 2024-02-09
ECD423-T-003 | Multiple Transceivers Communication Test | I,T | O, SC | ECD423-R-008 ECD423-G-001 | 2024-03-01
ECD423-T-004 | Tilt Sensor Test | A,I | SC | ECD423-R-009 ECD423-R-010 | 2024-03-08
ECD423-T-005 | Rotary Encoder Test | D | SC | ECD423-R-006 ECD423-R-007 ECD423-R-009 ECD423-G-004 | 2024-03-08
ECD423-T-006 | Keypad Rotation Test | I,D,A | SC | ECD423-R-005 ECD423-R-006 ECD423-R-007 ECD423-R-009 ECD423-G-004 | 2024-03-15
ECD423-T-007 | Instrument Transition Test | D | SC | ECD423-R-007 ECD423-G-004 | 2024-03-22
ECD423-T-008 | Variable Volume Test | D,I | SC, O | ECD423-R-003 ECD423-R-004 | 2024-03-01
ECD423-T-009 | Lamellophone Key Test | D,I | SC | ECD423-R-003 ECD423-G-005 | 2024-03-08
ECD423-T-010 | Joystick Test | D | SC | ECD423-R-002 | 2024-03-15
ECD423-T-011 | Final Test | D | SC, EI | All Requirements | 2024-03-22

6 System Verification Tests

### Communications Test Group Overview

This test group includes all wireless communication tests and the outputting of MIDI messages.

### Test Procedures

#### ECD423-T-001 MIDI Test

This test is implemented with the help of the Teensy 4.0 device which is connected to a computer via USB connection. The purpose of this evaluation is to demonstrate the ability to send MIDI signals which emit notes with varying variable volume control and pitch bend. Additionally, the program should switch between different channels. This is done by programming the microcontroller with code from Arduino IDE. This code utilizes built in functions from the Control Surface Library to create for loops which demonstrate scaling of the notes ranging from 0-127. An additional two for loops are used to show variable volume ranging from values 0-127 and pitch bend. The results of this program are shown through the monitor on the synthesizer program, Element.

# | Step-by-Step Operations | Expected Results | Actual Results

1 | Connect Teensy 4.0 to the computer via USB connection. | No results expected as this is setup
2 | Open, verify and upload the program used to demonstrate this test. | The Arduino IDE Serial Monitor should display which channels are currently on/off at any given time in addition to their volume, and note being sent.
3 | Open the synthesizer program, Element. Go to File>Preferences>MIDI and turn “Active MIDI inputs” on. | All current results are maintained with no added changes made.
4 | Turn your volume to the appropriate range and start observing the MIDI monitor. | There should be a total of 3 MIDI monitors displaying the current note, pitch bend, and volume control at any given time on the synthesizer.

#### ECD423-T-002 Wireless Communication Distance Test

This test will ensure that both keypads can send wireless messages to the base station reliably without transmission errors. Additionally, the wireless modules must be able to maintain communication of up to 50 inches. This test consists of two Arduino Nano’s/Teensy with nRF24L01 transceivers transmitting data and 1 Teensy 4.0 with a nRF24L01 transceiver receiving the data. The transmitters will slowly be moved away from the source until the receiver can no longer reliably receive data. An evaluator will stop and record the distance between modules once the connection has been broken.

# | Step-by-Step Operations | Expected Results | Actual Results

1 | Connect the 2 Nano’s/Teensy’s and 1 Teensy 4.0 to their respective nRF24L01 modules. | No results expected as this is setup
2 | Connect the Teensy 4.0 to one laptop and both Nano’s/Teensy’s to another. Note, for this experiment the Nano’s/Teensy’s and Teensy must not be using the same laptop unless you have cables that can extend at least 50 inches in width. | No results expected as this is setup
3 | Open, verify and upload the code for the transceivers to the Nano’s/Teensy’s and the code for the receiver to the Teensy. | Serial Monitor should display that the program has finished set up.
4 | Have person A look at the Serial Monitor on the Arduino IDE and person B to move the Nano’s/Teensy’s away from the Teensy at a steady pace. When the connection is broken, person A will tell person B to stop. Person B will measure the distance from the Teensy to the Nano/Teensy. | Person A should see on the Serial Monitor for the receiver code, the message being received. When the message to be received is displaying “No msg received” for an extended period of time. Person B should record the distance between the wireless modules and check to see that the distance is at least 50 inches apart.

#### ECD423-T-003 Multiple Transceivers Communication Test

This is a test performed with the sole purpose of connecting two transceiver modules to a single receiver module for constant uni-directional communication. Each transceiver module will be attached to each keypad respectively and the receiver module will be located at the base station. The strength of transmission signals will be recorded based on the frequency of failed transmission. The average time to transmit each signal will be taken into consideration in regards to evaluating the quality of this communication.

# | Step-by-Step Operations | Expected Results | Actual Results

1 | Connect the 2 Nano’s and 1 Teensy 4.0 to their respective nRF24L01 modules. | No results expected as this is setup
2 | Connect the Teensy 4.0 to one laptop and both Nano’s to another. Note, for this experiment the Nano’s and Teensy must not be using the same laptop unless you have cables that can extend at least 50 inches in width. | No results expected as this is setup
3 | Open, verify and upload the code for the transceivers to the Nano’s and the code for the receiver to the Teensy. Make sure to type “R” into the Serial Monitor for the receiver and different node addresses, from 0-5, for each transceiver. | The Serial Monitor for the receiver should recognize it is in receiving mode and that of the transceiver should start sending transmission signal’s with payload ID.
4 | Observe the Serial Monitor for both transceivers and determine the average time to transmit signals for each. Take note of the max value observed from the Serial Monitors. | The transceiver should be taking on average 580-600us to transmit signals. single transmission time should not exceed 10ms.
5 | Have one person continuously read the payload ID on the receiver side to determine if there are any missed transmission signals. | The receiver should be receiving almost all of the messages being sent. This can be observed since the payload ID’s for each transmission signal increases by a factor of 1.

### Position Test Group Overview

This test group handles the tests that require physical adjustments to the instrument.

#### ECD423-T-004 Tilt Sensor Test

The test will be performed by attaching our tilt sensor to the microphone stand and then tilting the rod of the stand to desired tilt level and seeing if the correct value is read. Light shaking will be applied to the rod also at each tilt position to make sure no false readings occur. The tilt sensor will be attached to a Teensy 4.0 which will read the sensor. The results of this test will determine how accurate our tilt sensor can be to detect current position.
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

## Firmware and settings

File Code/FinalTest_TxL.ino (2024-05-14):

/*
  Programmer: Jolin Lin
  ECD 423 - Novel MIDI Instrument (Senior PRJ)
  Date: 04/24/2024
  Purpose: This program is a continuation of demo11_rotaryEncoder by receiving values
            from the rotary encoder, tilt sensor and rotational sensor to switch
            between instruments(channels). Tilt sensors are directly connected to the 
            based station using a wire.
*/

#include <SPI.h>
#include <RF24.h> 
#include <light_CD74HC4067.h> //library for mux
#include <Encoder.h>  //lib for Teensy

RF24 radio(9,10); // nRF: CE,CSN

// Analog and digital pins below
const int MUX_ENABLE = 8;
const int S0 = 4;
const int S1 = 3;
const int S2 = 2;
const int S3 = 1;
const int ROTENC1 = 6;  //Rotary Encoder
const int ROTENC2 = 7;
const int ROTPLATE1 = 17;
const int ROTPLATE2 = 18;
const int ROTPLATE3 = 19;
const int SIG = A6; 
const int JOYSTICK = A8; 

CD74HC4067 mux(S0,S1,S2,S3); //creates a new object
Encoder myEnc(7,6); 

// struct to send all 7 FSR data to the base station
struct DataSig{
  bool lOrR;          
  uint16_t fsr0;
  uint16_t fsr1;
  uint16_t fsr2;
  uint16_t fsr3;
  uint16_t fsr4;
  uint16_t fsr5;
  uint16_t fsr6;
  int16_t rotEncoder; 
  bool rotPlate1; //Rotational Plate Sensors
  bool rotPlate2;
  bool rotPlate3;
  int16_t joystick;
};

//initalize struct
struct DataSig dataSigSend = {0,0,0,0,0,0,0,0,0,0,0};

//Function to assign fsrDataSig to appropriate int within struct dataSigSend
void setStructData(int fsrDataSig, int i){
  if(i == 0b0000){
    dataSigSend.fsr0 = fsrDataSig;
  }
  else if(i == 0b0001){
    dataSigSend.fsr1 = fsrDataSig;
  }
  else if(i == 0b0010){
    dataSigSend.fsr2 = fsrDataSig;
  }
  else if(i == 0b0011){
    dataSigSend.fsr3 = fsrDataSig;
  }
  else if(i == 0b0100){
    dataSigSend.fsr4 = fsrDataSig;
  }
  else if(i == 0b0101){
    dataSigSend.fsr5 = fsrDataSig;
  }
  else if(i == 0b0110){
    dataSigSend.fsr6 = fsrDataSig;
  }
  else{
    Serial.println("Not updating anything");
  }
}

void setup() {
  Serial.begin(9600);
  pinMode(ROTPLATE1, INPUT_PULLUP); //Pull up resistors for rotational plate
  pinMode(ROTPLATE2, INPUT_PULLUP);
  pinMode(ROTPLATE3, INPUT_PULLUP);
  
  radio.begin(); // Starts the NRF24L01
  radio.openWritingPipe(0xABCDEF12); 
  radio.setPALevel(RF24_PA_MIN);
  Serial.println("-------------------------Program Start------------------------");
}

int16_t iterate = 0;
int16_t z=0;

void loop() {
  int16_t newPosition = myEnc.read();
  if(newPosition != dataSigSend.rotEncoder){
    dataSigSend.rotEncoder = newPosition;
  }

  //read joystick value
  dataSigSend.joystick = analogRead(JOYSTICK);

  //reading rotational plate sensors
  dataSigSend.rotPlate1 = digitalRead(ROTPLATE1);
  dataSigSend.rotPlate2 = digitalRead(ROTPLATE2);
  dataSigSend.rotPlate3 = digitalRead(ROTPLATE3);
  
  digitalWrite(MUX_ENABLE, HIGH);
  // for each iteration of the main loop, i increases from 0-6 back to 0
  mux.channel(iterate);
  int val = analogRead(SIG); 

  //assign val to appropriate fsr# within struct dataSigSend
  setStructData(val, iterate); 
  digitalWrite(MUX_ENABLE, LOW);

  //set LeftOrRight to 0
  dataSigSend.lOrR = 0;

  //increase value of i 
  iterate += 1;
  if(iterate >= 7){
    iterate = 0;
    radio.write(&dataSigSend, sizeof(dataSigSend));
    Serial.println("Mux Values: " + String(dataSigSend.fsr0) + ", " + String(dataSigSend.fsr1) + ", " + String(dataSigSend.fsr2) + ", " + String(dataSigSend.fsr3) + ", " + String(dataSigSend.fsr4) + ", " + String(dataSigSend.fsr5) + ", " + String(dataSigSend.fsr6));
    Serial.println("Rotational Sensors: "+String(dataSigSend.rotPlate1)+", " + String(dataSigSend.rotPlate2) + ", " + String(dataSigSend.rotPlate3));
    Serial.println("RotaryEncoder Val: "+String(dataSigSend.rotEncoder));
    Serial.println("Joystick Val: "+String(dataSigSend.joystick));
    Serial.println("");
  }
  delay(2); //slight delay to prevent multi-Tx data signals from cancelling each other out
}

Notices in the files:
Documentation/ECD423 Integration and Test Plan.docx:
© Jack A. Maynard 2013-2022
